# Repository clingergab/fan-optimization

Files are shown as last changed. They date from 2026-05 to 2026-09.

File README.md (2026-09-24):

# fan-optimization

A 3D-printed folding hand fan designed by optimization: Bayesian optimization over 3D unsteady CFD picks
the blade shape, then 3D topology optimization hollows each winning blade into a printable part.

<p align="center">
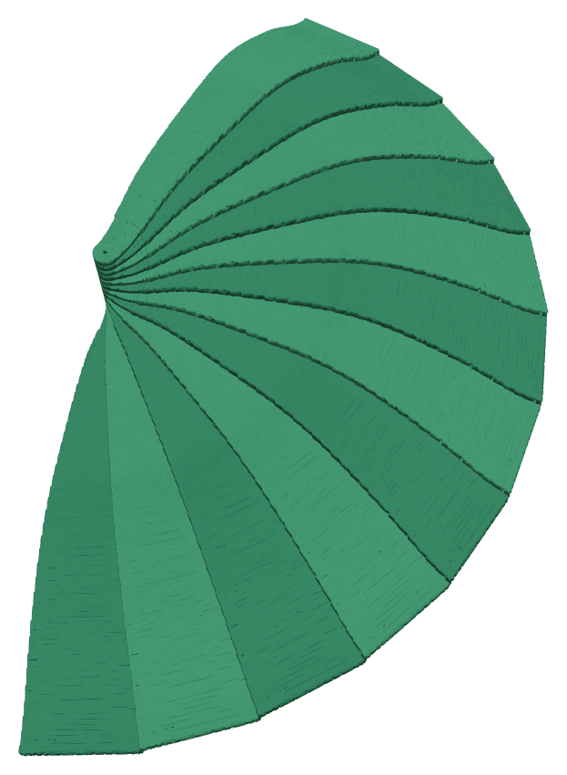
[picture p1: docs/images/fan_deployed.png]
Deployed 12-blade fan
  
  &nbsp;&nbsp;
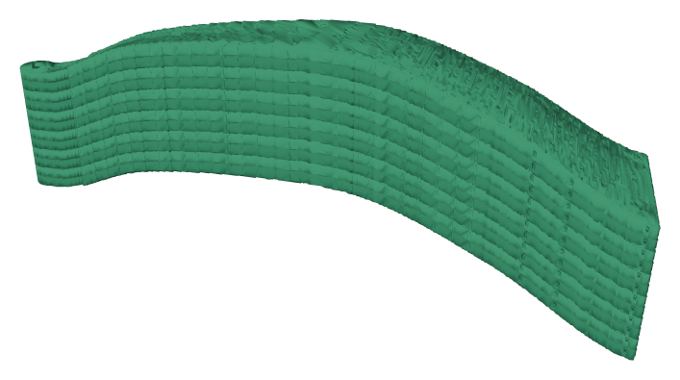
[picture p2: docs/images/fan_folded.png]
Folded 12-blade stack
  
</p>

## Pipeline

1. **Geometry** — CadQuery blade from a 33-parameter codec (rib wave, panel shape, thickness); 12 blades must fold into a ≤ 90 mm stack.
2. **CFD** — SU2 unsteady 3D simulation of the ±40°, 2 Hz stroke; objective `J_fan` = cycle-mean thrust.
3. **Optimization** — BoTorch (qLogNEHVI + TuRBO) over wind ↑, mass ↓, deflection ↓, run across parallel Colab sessions.
4. **Verification** — top designs re-run at fine CFD resolution.
5. **Topology optimization** — per-blade 3D SIMP carves the interior while keeping the aero surface.
6. **Print** — marching cubes → watertight STL → Bambu Studio.

## Status

V1 is done computationally: three blades are ready to print ([print guide](docs/print_guide.md),
[STL files](https://github.com/clingergab/fan-optimization/releases/tag/v1.0-print),
[3D previews](docs/models/)). Next is printing and a blinded feel test against a flat-blade baseline.
V2 plans are in the [backlog](docs/V2_backlog.md).

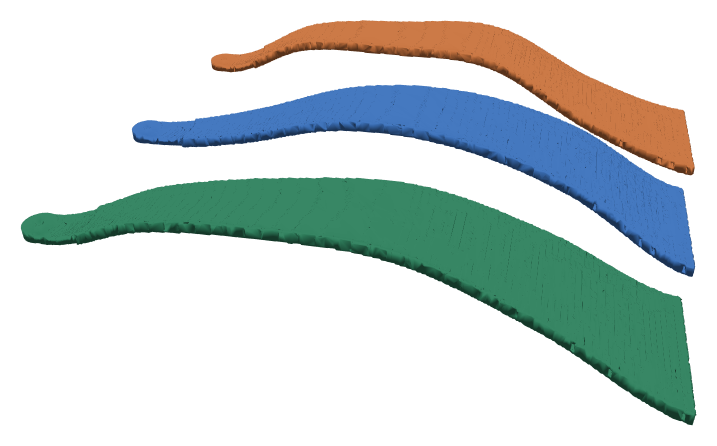
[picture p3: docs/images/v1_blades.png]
The three V1 blades


## Quick start

```bash
conda env create -f environment.yml && conda activate fanopt
pip install -e ".[dev]"
pytest
```

CFD and topology-optimization runs live in [`notebooks/`](notebooks/README.md) (Colab). Design decisions
are in [`docs/adr/`](docs/adr/README.md).

## License

MIT

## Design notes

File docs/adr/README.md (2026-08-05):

# Architecture Decision Records (ADRs)

**This is the single entry point for "what is the current design decision?"** The docs in this
repo accumulated across several major pivots (R11 → V1-slim → aero-first redesign → the 3D-
objective redo). To avoid conflicting or confusing guidance, **read the CURRENT decision for
each topic below**, then follow the supersession chain only if you need the history.

**Convention (lightweight, adopted 2026-07-26):** each major design decision is an ADR with a
Status — *Proposed / Accepted / Superseded*. A new decision that overrides an old one names it
under **Supersedes**; the superseded ADR is marked here and forward-points in its own banner.
Long-form legacy docs are retrofitted as ADRs **by reference** in the ledger below rather than
rewritten. We are not back-filling full ADR files for historical decisions — the ledger + the
current-decision table are enough to avoid confusion.

---

## CURRENT decision, by topic — read these

| Topic | Current decision | Where |
|---|---|---|
| **Optimization approach** (objective, fidelity, BO) | **ADR-0004** — redo on a correct 3D objective (CFz thrust, whole-fan periodic cascade, cold-start coarse→fine BO) | [`0004-optimization-3d-objective-redo.md`](0004-optimization-3d-objective-redo.md) |
| **Blade geometry / architecture** | **ADR-0003** — aero-first solid blade (surface-of-revolution, thick rib + thin panel, N_RADIAL_SECTIONS=40) | [`../blade_architecture_redesign.md`](../blade_architecture_redesign.md) |
| **Phase-2 structural TO** | **ADR-0007** — per-design 3D SIMP on each solid blade (freeze aero skin, carve rib/interior); supersedes the 2D representative-rib TO | [`0007-phase2-per-design-3d-blade-to.md`](0007-phase2-per-design-3d-blade-to.md) |
| **Locked constants** (geometry / kinematics / CFD) | unchanged by the pivot | [`../locks_index.md`](../locks_index.md) |
| **Unsteady CFD regime** | **MACH=1e-9 compressible** (V1, `../locks_index.md §9.4.1`); switch to incompressible **proposed for V2** | [`0006-unsteady-cfd-regime-incompressible.md`](0006-unsteady-cfd-regime-incompressible.md) |
| **Product scope / V1↔V2 split** | unchanged | [`../phase_logs/phase_0_signoff.md`](../phase_logs/phase_0_signoff.md) |
| **V2 / deferred ideas** | backlog | [`../V2_backlog.md`](../V2_backlog.md) |

If two docs seem to conflict, the table above wins.

---

## ADR ledger (supersession chain, newest first)

- **ADR-0008 — Aero BO ranked on rigid geometry (flex-blind ranking)** (2026-08-04). Doc:
  [`0008-flex-blind-aero-ranking.md`](0008-flex-blind-aero-ranking.md).
  **Status: ✅ ACCEPTED — known-limitation record.** Annotates ADR-0004 (does NOT supersede it): the V1
  aero BO ranked designs by `J_fan` on the **rigid** blade (the §2.3 "No FSI" lock), but the panel flexes
  5–15 mm under aero (§3.1) and flex is likely **differential** across designs — so the V1 selection
  *order* is unverified against flex. Fidelity gap, not a wrong-objective error. V1 proceeds (the feel
  test judges the real flexing blade); V1.5/V2 action = one-way FSI across a stiffness spread, re-rank
  finalists before any BO redo. Tracked in `../V2_backlog.md`.
- **ADR-0007 — Phase-2 per-design 3D blade TO** (2026-08-02). Doc:
  [`0007-phase2-per-design-3d-blade-to.md`](0007-phase2-per-design-3d-blade-to.md).
  **Status: ✅ ACCEPTED — CURRENT.** Supersedes the Phase-2 TO *approach* of ADR-0001 /
  `report-final.md` (single 2D representative-rib SIMP by symmetry) — the aero-first solid blade
  (ADR-0003) has no single representative rib, so TO runs **per-design 3D SIMP** on each of the
  top-10 winners (freeze the aero skin, carve rib cores + interior). Retires
  `scripts/run_phase2_to.py`. Geometry, locks, and the optimization redo (ADR-0004) are unaffected.
- **ADR-0006 — Unsteady CFD regime → incompressible** (2026-08). Doc:
  [`0006-unsteady-cfd-regime-incompressible.md`](0006-unsteady-cfd-regime-incompressible.md).
  **Status: 🕐 PROPOSED (V2).** Does not change V1. Would supersede the unsteady-tier MACH=1e-9 regime in
  `../locks_index.md §9.4.1` (Round-9 HIGH-12) if accepted — switching the pitching-fan tier from
  compressible-forced-to-MACH=1e-9 to a truly incompressible solver to remove the low-Mach stiffness that
  drives the ~3h eval cost + divergences. From the `docs/audit_2026-08_toolchain_and_approach.md` retrospective.
- **ADR-0004 — Optimization redo on a 3D objective** (2026-07-26). Doc:
  [`0004-optimization-3d-objective-redo.md`](0004-optimization-3d-objective-redo.md).
  **Status: ✅ ACCEPTED — CURRENT.** Supersedes the *optimization approach* of ADR-0001 and
  ADR-0002. Trigger: an audit found the 2D-slice objective was blind to the rib wave and the 3D
  verification measured the wrong force axis (CFx not CFz) — no design was ever optimized for
  wind. Geometry (ADR-0003), locks, and product goal are unaffected.
- **ADR-0003 — Aero-first blade redesign** (2026-07-19). Doc:
  [`../blade_architecture_redesign.md`](../blade_architecture_redesign.md).
  **Status: ✅ ACCEPTED.** The solid surface-of-revolution blade. Geometry is trustworthy and
  unaffected by ADR-0004; only the scoring layer around it was broken.
- **ADR-0002 — V1-slim** (2026-07-02). Doc: [`../plan_v1_slim_latest.md`](../plan_v1_slim_latest.md).
  **Status: ⚠️ SUPERSEDED IN PART** by ADR-0004. Its single-2D-slice optimization was found
  invalid; its V1↔V2 split and non-optimization scope still hold.
- **ADR-0001 — R11 comprehensive plan** (2026-05-12). Doc: [`../report-final.md`](../report-final.md).
  **Status: ⚠️ SUPERSEDED** by ADR-0002 (for V1 scope) — historical reference only. (Ironically
  its multi-fidelity BO *with 3D tiers* is closer to ADR-0004 than V1-slim's 2D-only cut was;
  the 2D-only shortcut is what caused the waste.)

---

## Adding a new decision
Create `adr/NNNN-slug.md` (next number), set **Status**, list what it **Supersedes**, mark the
superseded ADR here and add a forward-pointing banner to its doc, and update the
**current-decision-by-topic** table above. Keep decisions immutable once Accepted — a change is
a *new* ADR that supersedes, not an edit.

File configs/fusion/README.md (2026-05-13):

# Spike 0.1 — Fusion headless add-in workflow on macOS

**Spec reference:** `docs/plan_R11.md §Phase 0 Spike 0.1` (lines 1785-1789)

**Question:** Can Fusion 360 be driven headlessly from a Python script on
macOS — read `params.json`, regenerate the model, export per-blade STL files
and a STEP file?

**Pass criterion (Spike 0.1):** Fusion launches via the CLI flag, executes
`fan_script.py` against an open one-blade test file, applies User Parameters,
and writes a `SPIKE_0_1_PASS.json` marker plus the requested STL / STEP files
without manual UI interaction.

**Fallback if it fails:** CadQuery becomes the sole geometry backend. Fusion
keeps a role as viewer + post-print manufacturable cleanup but never appears
in the optimization loop.

---

## What's here

| File | Purpose |
|---|---|
| `fan_script.py` | The Fusion script. `run(context)` reads `params.json`, applies User Parameters on the active document, exports STL (per body) + STEP, writes a PASS/FAIL marker. |
| `fan_script.manifest` | Add-in manifest. Use only if you install as an add-in rather than running as a one-shot script. |
| `params.example.json` | Example parameter file. Copy to `params.json` before running. |
| `../../scripts/run_spike_0_1.py` | Headless driver. Validates prerequisites, invokes Fusion with `--runScript`, polls for the marker, reports pass/fail. |
| `../../docs/phase_logs/spike_0_1.md` | Protocol log — fill in as you run. |

---

## Prerequisites

1. **Fusion 360 installed** at the default macOS location:
   `/Applications/Autodesk Fusion 360.app` (or the Fusion 360 admin install).
   The driver script accepts an override path via `--fusion-app`.
2. **A one-blade test file open in Fusion** with these User Parameters
   defined (Fusion → Modify → Change Parameters):
   - `L_blade`, `panel_thickness`, `rib_base_width`, `rib_tip_width`,
     `rib_thickness`, `hub_radius`, `rib_tip_taper`, `pivot_center_x`,
     `click_chamfer_dim`.

   If your test file uses different names, edit `params.example.json` (or
   `params.json` after you copy it) to match — unknown names are recorded
   but not fatal, so partial coverage still produces an export.

   *If you don't yet have a test file:* create a minimal one with a single
   sketched rectangle (`L_blade` × something) extruded by `panel_thickness`.
   Spike 0.1 only validates the workflow plumbing; the geometry detail
   matters in Spike 0.7 (generative-geometry sanity check), not here.

3. **Save the test file once before running** so Fusion has a parent
   document to compute against.

---

## How to run (3-minute procedure)

```bash
cd ~/Projects/fan-optimization

# 1. Copy the example params to the live name (only once)
cp configs/fusion/params.example.json configs/fusion/params.json

# 2. (Optional) edit configs/fusion/params.json with the parameter
#    values you want this run to test

# 3. Open your one-blade test file in Fusion 360 and make it the active
#    document. (Fusion cannot open documents headlessly on macOS — see
#    "Headless caveats" below.)

# 4. Run the driver
python scripts/run_spike_0_1.py

#    The driver:
#      a. confirms Fusion.app exists
#      b. confirms configs/fusion/params.json exists
#      c. clears any stale marker in data/meshes/spike_0_1/
#      d. invokes Fusion with `--runScript configs/fusion/fan_script.py`
#      e. polls for SPIKE_0_1_PASS.json or SPIKE_0_1_FAIL.json
#      f. prints the marker summary and exits with 0 (pass) / 1 (fail)
```

Expected output on success:

```
[spike_0_1] Fusion: /Applications/Autodesk Fusion 360.app/Contents/MacOS/Autodesk Fusion 360
[spike_0_1] params:  configs/fusion/params.json
[spike_0_1] launching Fusion --runScript ...
[spike_0_1] polling for marker (timeout 120 s)
[spike_0_1] PASS — wrote 1 STL + 1 STEP to data/meshes/spike_0_1/
```

---

## Headless caveats (the truth about macOS Fusion)

Fusion 360 on macOS is **not fully headless**. The CLI workflow:

1. Fusion's GUI launches (briefly, can be backgrounded with `open -g`).
2. Fusion loads whatever document is set as the active document — it does
   NOT auto-open a path passed as an argument.
3. The `--runScript` flag executes the named `.py` against the active
   document's Python API context.
4. The script writes its outputs to disk.

Consequences:

- **You must have the test document open in Fusion before you launch
  the driver.** That's the one piece of manual setup. Once it's open,
  the rest is scripted.
- A Fusion window will flash on screen. The driver uses `open -ga "..."
  --args --runScript ...` so it stays backgrounded, but it isn't true
  invisible-headless.
- If you log out / lock the screen during the run, Fusion may stall. Run
  the spike with the user session active.

If Fusion proves too brittle for unattended Phase 4 / Phase 5 batch use,
the spike fail-action is the locked fallback per `§Phase 0 Spike 0.1`:
**CadQuery becomes the sole geometry backend**, Fusion drops to
viewer/cleanup. The fallback path is pre-wired — `src/fanopt/geometry/`
already plans on CadQuery as primary per §3.2 / §9.7.

---

## AppleScript fallback (not implemented for the spike)

The spec lists "fall back to AppleScript UI automation if needed." That
path would script the Fusion GUI through `osascript`:

```applescript
tell application "Autodesk Fusion 360"
    activate
    -- click menu items, type into the parameter dialog, save, export
end tell
```

It's documented here for completeness but **not implemented in this
commit** — if `--runScript` works (the spec's primary path), AppleScript
adds complexity without benefit. Implement only if Spike 0.1's primary
path fails and the fallback decision is to retain Fusion as backend.

---

## Troubleshooting

| Symptom | Likely cause | Fix |
|---|---|---|
| `SPIKE_0_1_FAIL.json: No active Fusion Design document` | The test file isn't open / isn't the active tab | Switch to the test file's tab in Fusion before launching the driver |
| `params.json not found` | Didn't copy the example | `cp configs/fusion/params.example.json configs/fusion/params.json` |
| `missing_parameters` in PASS marker is non-empty | Your User Parameter names differ from the keys in `params.json` | Either rename the Fusion User Parameters, or edit `params.json` to match |
| Driver times out after 120 s | Fusion is hung / your script crashed before reaching `_write_marker` | Open Fusion → Scripts and Add-Ins → Run `fan_script.py` manually; a dialog will show the traceback |
| `Authorization required` dialog from macOS | First-time launch consent | Click Allow once; persists |

---

## What to record in `docs/phase_logs/spike_0_1.md`

After the run, fill in:
- Pass / fail.
- Wall-clock time from driver launch to marker.
- Any `missing_parameters` (schema drift to fix before Phase 1).
- One-line manufacturability eyeball check on the exported STL.

A pass closes Spike 0.1 and unlocks the parallel Spike 0.2-0.5 workflow.
A fail triggers the fallback decision in the next phase-log entry.

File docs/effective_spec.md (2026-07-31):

# Effective Spec (human-readable mirror of `effective_spec.yaml`)

This document is a flattened, current-state-only view of every locked decision in the project. It contains **no history, no superseded options, no amendment cross-references** — those live in Appendix D of `../report-final.md` for traceability.

**Single source of truth:** all production code, CI tests, SU2 templates, and Phase-N launch scripts read from `effective_spec.yaml`. This `.md` file is a human-readable rendering of the same data; the YAML is canonical when the two disagree (CI test `tests/test_audit/test_effective_spec_consistency.py` enforces this).

When a spec changes: update `effective_spec.yaml` first, then this `.md`, then `../report-final.md`. CI fails if test fixtures or code constants reference a value that differs from `effective_spec.yaml`.

**Schema version: 3** (bumped 2026-05-12; v2→v3 covers the C-series sign + projection corrections, H-series operational policies, M-series wording and locking, L-series schema fixes, plus the Z-crank rib-containment + heteroscedastic-purge + JSONL-nullable cleanup batch).

---

> **⚠ SUPERSEDED BY ADR-0005** (trapezoid blade redesign, 2026-07-29..30) — see
> `adr/0005-trapezoid-blade-geometry-redesign.md`. The V1 aero blade is now a **220 mm
> surface-of-revolution TRAPEZOID** (root = 12 mm boss dia at r=0, tip ≈ 51 mm), not the pie-slice
> V-unit. Live overrides of the values below: blade length **200 → 220 mm** (live tip =
> `geometry.blade.RIB_TIP_RADIUS_M`), **blade_count fixed 12** (the {8,10,12} bandit dropped, span
> ≈ 43 cm), **L_wrist_to_tip 0.25 → 0.27 m**, **V_tip 2.20 → 2.37 m/s**, **CFD Re → 43000 / Mach
> 0.0070**, pie-slice width (`r·Δθ`) → Cartesian trapezoid, **mass cap 300 g** (`MAX_TOTAL_MASS_KG`;
> the 100 g C9 text is superseded). The legacy 200 mm values below still drive the retired
> 2D-slice / plano-convex / rib-TO stack.

## Architecture

- **Blade type:** V-unit (2 ribs + 1 panel) — **LEGACY; superseded by the ADR-0005 trapezoid for the live aero path**
- **Material:** single-material PETG except **steel or brass** pivot pin (~2.5 g; PETG pin not permitted)
- **Default n_blades:** 10 legacy → **fixed 12 live (ADR-0005)** (the {8, 10, 12, 14} bandit is dropped)
- **L_blade:** 200 mm legacy parametric length → **live aero blade 220 mm (ADR-0005)**
- **L_wrist_to_tip:** **270 mm** (d_handle + live 220 mm blade tip; **canonical lever arm for τ→F conversions**; ADR-0005, was 250 mm)
- **Pivot architecture:** pin through panel at y = 0; ribs carry no pivot holes.
- **Pivot center (base-relative):** `pivot_center_x = 8 mm`
- **Boss:** 12 mm-OD circular boss × `panel_thickness` centered at `(pivot_center_x, 0)`
- **Keep-out:** `pivot_keep_out_radius = 7 mm` → PANEL_PIVOT_REGION (circular mask)
- **Pin:** 3 mm steel or brass rod, ≥ 45 mm long
- **n_panels_stacked:** 10
- **Wrist axis:** +y
- **Wrist origin:** world (0, 0, 0); pivot at (+0.05, 0, 0). Locked single convention.
- **d_handle:** 0.05 m

## Dimensions and ranges

| Quantity | Value |
|---|---|
| Rib width (base / tip) | 12 / 6 mm |
| Rib thickness | 2.0 mm |
| Panel width between ribs (at pivot end) | 6-8 mm |
| Blade tangential width at radius r | `r · 0.232 − 2·rib_width(r) − 0.5 mm` (panel widens with r) |
| **Panel thickness control points** | **2.2-3.8 mm** (cleanup lock — lower bumped from 2.0 to give the click chamfer 0.1 mm Z-clearance on each side) |
| Panel thickness named derivations | `panel_thickness_pivot`, `panel_thickness_tip`, `panel_thickness_max`, `panel_thickness_mid` |
| Deployed fan extent | **12 × 13.3° ≈ 159.6°** (ADR-0005: blade_count fixed at EXACTLY 12, never more or less; span ≈ 43 cm over the 220 mm blade). Legacy: 10 × 13.3° = 133.3°. |
| Inter-blade angle | 13.3° |
| Folded stack (12 blades) | ≤ 90 mm (ADR-0005 `MAX_FOLDED_STACK_HEIGHT_M`; legacy 10-blade was 22-42 mm) |

## Click features

- **Engagement:** Z-direction lap **with crank z-contained in the rib's z-extent** — `|z_click − z_rib_midplane| ≤ rib_thickness/2 = 0.001 m` (cleanup lock; prevents folded-state collision with adjacent blade's panel)
- **Chamfer angle:** 45° on the rib's top/bottom z-face
- **Chamfer overlap:** 0.5-1 mm
- **Chamfer clearance per side:** 0.1 mm (sets `panel_thickness_min = rib_thickness + 0.2 = 2.2 mm`)
- **Detent radius:** 0.3-0.5 mm
- **Design clearance:** 0.15-0.20 mm per mating surface
- **Naming:** `click_detent` (bare word `detent` reserved for V2-deferred locking)

## Kinematics (H8 symbol-table lock)

| Symbol | Value | Used at |
|---|---|---|
| `f_wave` | 2 Hz | §3.2.3, §9.4 |
| `T_cycle` | 0.5 s | §9.4 |
| `θ_max` | 0.6981 rad (40°) | SU2 PITCHING_AMPL |
| `ω_SHM` | 12.566 rad/s | SU2 PITCHING_OMEGA |
| `ω_blade_max` | 8.8 rad/s | V_tip, V_local |
| `α_max` | 110 rad/s² | §2.4, Filter 2 |
| `V_tip` | 2.37 m/s (ADR-0005; was 2.20) | Re_global, Mach |
| `V_local(r)` | `ω_blade_max · r_wrist` | §3.2.4 BL, C6 multi-radius |
| `Re_global` | 43000 (Tier 0/1; ADR-0005, was 37000) | SU2 cfg |
| `k_reduced` | 0.57 | §3.2.3 |
| `L_blade` | 0.20 m legacy → live 0.22 m (ADR-0005) | TO domain |
| `L_wrist_to_tip` | **0.27 m** (ADR-0005; was 0.25) | **all torque→force conversions** |

**Lever-arm audit:** torque-to-force conversions outside the pivot region MUST use `L_wrist_to_tip = 0.27 m` (ADR-0005; = d_handle + live 220 mm blade tip), NOT `L_blade`.

## SU2 / CFD lock (C2 sign convention)

| Key | Value |
|-----|---|
| MACH_NUMBER (steady tiers) | 0.0070 (ADR-0005; was 0.0064) |
| REYNOLDS_LENGTH (Tier -1) | 0.20 m |
| REYNOLDS_LENGTH (Tier 0, Tier 1) | 0.27 m (ADR-0005; was 0.25) |
| REYNOLDS_NUMBER (Tier -1 / 0/1) | 18000 / 43000 (ADR-0005; was 37000) |
| MOTION_ORIGIN | (0, 0, 0) (wrist-grip at world origin) |
| **PITCHING_OMEGA_AXIS** | (0, 1, 0) — **TIER_SPECIFIC[1] only** (L5 lock; Tier -1/0 have no pitching motion) |
| **PITCHING_AMPL_AXIS** | (0, 1, 0) — TIER_SPECIFIC[1] |
| PITCHING_OMEGA magnitude / AMPL | 12.5664 rad/s / 0.6981 rad |
| AMPL unit | radians (pinned via SU2 build commit; verified by amplitude assertion) |
| **FREESTREAM_PRODUCTIVE** (C2) | **(0, 0, -1)** — air flows -z past stationary fan that's actually being swept in +z toward the user |
| **FREESTREAM_RETURN** (C2) | **(0, 0, +1)** |
| Unsteady ambient velocity (Tier 1) | ≈ 0.001 m/s (near-zero; H10 fallback if FREESTREAM_VELOCITY unsupported: `MACH_NUMBER=1e-9 + REF_DIMENSIONALIZATION=FREESTREAM_PRESS_EQ_ONE`) |
| TIME_STEP / MAX_TIME / TIME_ITER | 0.0025 s / 2.5 s / 1000 |
| n_cycles | 5 (extend to 8 if cycle-2-vs-3 > 5%) |
| J_fan SE | `std / √(n_cycles − 1)` — **diagnostic only, NOT fed to GP** |
| CFL_NUMBER / retries | 10.0 / 1 (halve on retry) |

## J_fan integration (C2 sign-correct two-eval delta)

- Plane Σ: 600 × 600 mm at 300 mm forward of the pivot along +z
- ρ_freestream: 1.225 kg/m³
- t̂ = +ẑ (explicit; **NOT** anatomical "from pivot toward user" phrasing)
- Cycles discarded: 1; integrate cycles 2 through N
- Cycle-2-vs-3 trigger: 5%, floored as `rel = |J2-J3| / max(|J2|, |J3|, 0.10·J_baseline)`
- **Steady-proxy** (C2): `J_fan_steady_proxy = Drag_productive − Drag_return`. A productive louver scores positive. The earlier "Drag_forward − Drag_backward" with `forward = (0,0,+1)` was inverted.

## Material constants

| Symbol | Value |
|---|---|
| ρ_PETG / σ_y_XY / σ_y_Z | 1270 kg/m³ / 45 MPa / **30 MPa** |
| E_PETG_XY / E_PETG_Z | 1300 MPa / 1000 MPa |
| ρ_pin (steel / brass) | 7850 / 8500 kg/m³ |
| **BED_SURFACE** | **smooth_pei** (M13 — Bambu AP05 or equivalent Ra ≤ 5 µm; textured PEI NOT permitted) |
| **Filter 2 p_aero_reference** | **10 Pa** (M3 — fixed canonical baseline; NOT per-design CFD) |

## K_t hotspot table (8 hotspots; bearing 2.00 MPa binds canonical)

| Hotspot | K_t | Mode | Cyclic allowable |
|---|-----|---|---|
| Panel pivot — tension (XY) | 2.42 | tension | 5.58 MPa |
| Panel pivot — bending (XY) | 3.2 | bending | 4.22 MPa |
| Panel pivot — bearing (Z) | 1.5 | bearing | **2.00 MPa** (binds) |
| Click detent (XY) | 3.0 | mixed | 4.50 MPa |
| Click detent (Z-floor) | 3.0 | Z | 2.00 MPa |
| TPMS through-hole | 2.5 | tension | 5.40 MPa |
| Rib-panel fillet | 1.5 | bending | 9.00 MPa |
| Slot end (louver) | 2.0 | mixed | 6.75 MPa |

**§59.5 stress-test load (H9 stagnation pressure):** `p_uniform = p_stagnation_peak = ½·ρ_0·V_local_max² ≈ 3.0 Pa` (canonical); `p_stress_test = 2.5 · p_stagnation_peak ≈ 7.5 Pa`. `V_local_max = ω_blade_max · L_wrist_to_tip = 2.37 m/s` (ADR-0005; was 2.20 at the 0.25 m lever). The 2.5× multiplier stacks on top of the spatial-distribution conservatism of using stagnation pressure (NOT spatial-average F_peak / A_panel).

## Print-frame ↔ deployed-frame mapping (M15 single canonical table)

```
Print frame (build plate at z=0, build direction +z):
  - Bed-contact face: outward normal = -z (faces bed)
  - Top of print: outward normal = +z

Deployed frame (user at +z relative to fan):
  - Aero-functional face (productive +z toward user): outward normal = +z
  - Return-stroke face: outward normal = -z

Rib-flat print orientation:
  - Print bed-contact face → Deployed +z face (calibrated for wall roughness)
  - Print top → Deployed -z face (return; symmetric roughness model)
```

§N7 Check 14 (M1 reworded): "the panel's bottom face (bed-contact in print frame) has its outward normal pointing in −z (into the bed)." The calibrated face is the bed-contact face — no support scars; Ra ≈ 5-10 µm from layer lines + smooth-PEI contact.

## Constraints and Pareto

- m_total < 60 g; r_CoM_wrist ≤ 0.160 m (computed via **XZ-projection** to the +y wrist axis per C1 lock); manufacturability ≥ 0.5
- **4 Pareto objectives:** maximize J_fan (multi-fidelity CFD); minimize I_wrist about +y (deterministic; C4 rationale = peak felt torque, NOT cycle work); minimize peak panel-pivot stress (own fidelity chain); minimize folded form factor (deterministic)

## Filter 2 (three independent modes; H4 hotspot list)

| Mode | Location | Allowable |
|---|---|---|
| Bending | panel skin | 4.22 MPa |
| Tension | hole equator | 5.58 MPa |
| Bearing | pin bore (Z) | 2.00 MPa (binds) |

Hotspot tightening at 0.40× headroom for: **panel pivot all 3 modes + click detent + rib-panel fillet + slot ends + TPMS through-holes + Layer 3 primitive boundaries**. The earlier "any K_t feature within 3 mm of the rib axis" criterion missed the panel-pivot bearing (at y = 0) and is removed.

Tip-deflection prefilter: < 0.6 mm. Reference pressure: `p_aero_reference = 10 Pa` (M3 fixed constant; Filter 2 has no per-design CFD).

## Acquisition pipeline (two-stage MFMO)

1. **qMFKG on J_fan only** (the one objective with CFD fidelity tiers); chooses Tier -1/0/1.
2. **qNEHVI over all 4 objectives at target fidelity** using per-objective surrogates stitched into a ModelListGP.

Per-objective models: `J_fan` MF GP; `i_wrist` / `folded_form_factor` deterministic; `peak_pivot_stress` single-fidelity GP on Filter 2 closed-form.

## Bayesian optimization

| Key | Value |
|-----|---|
| N_DIMS | 37-46 |
| COST_TUPLE | (2.0, 10.0, 50.0) |
| HV_baseline | HV at round 200 (fixed) |
| HV early-stop floor | 500 rounds |
| HV 50-round gain threshold | 1e-4 · HV_baseline |
| Acquisition cap | 35 |
| **K seed at launch** (H3) | from **Phase 3 R²** (2D steady ↔ 2D unsteady): K=3 if ≥0.6; K=4 if 0.5≤R²<0.6; K=5 if <0.5 |
| **K running update during Phase 4** (H3) | from **Spearman ρ² on (Tier 0, Tier 1) overlap**, recomputed every 20 Tier-0 completions, once N ≥ 30 |
| K locked range | {3, 4, 5} (no K=2 path) |
| 1000-h fallback | hold K, force-grow Tier-1 overlap (NOT terminate) |
| ρ freeze threshold | 0.4 (general) / 0.2 (TPMS or noise) |
| GP noise | fixed-floor scalar per tier (NOT per-observation; **CI gate `test_no_heteroscedastic.py`** asserts no stale refs) |
| L7 Tier-1 bias diagnostic | within first 100 Tier-0 evals, if |Δ_TPMS / mean_J_fan_tier0| > 0.30 → switch TPMS/noise architectures to Tier-0-only promotion |

## H5 stop-criteria priority ladder

1. **HV plateau** (50-round gain / HV_baseline < 1e-4 after round 500) → converge + reallocate.
2. **1000-h cumulative compute** → K stays in {3, 4, 5}, force-grow (Tier 0, Tier 1) overlap. **CONTINUE Phase 4, NOT terminate.**
3. **1300-h pessimistic ceiling** → hard stop, hand off current Pareto.

If #1 and #2 fire simultaneously, **#1 wins**. If #2 fires and force-grow completes but BO has not converged by #3, terminate at #3.

## Campaign infrastructure

| Key | Value |
|-----|---|
| Parallel Colab sessions (locked) | 2-4 |
| SU2 procs per session | 5 |
| Retrain interval | 30 min |
| Slice size | 30-60 designs |
| Compute budget (expected/pess/fav) | 600-1100 / 1300 / 300-600 h |
| **Phase 0 sub-spike budget allocations** (H7) | NOT booked against the 1000-h Phase 4 stop rule: Spike 0.6c (H10) ≈ 12 h; Spike 0.7c (H7) 430 h; C6 radial-correction 50 h |
| Stop rule | 1000 h (counted from `git tag phase4-launch`, NOT Phase 0 start) |
| Slice file pattern | `slice_assignments_v{N}.json` (versioned everywhere) |
| Drive pointer format | two-version |
| **Cross-session claim post-open sleep** | **30 s** (M6 lock; bumped from 5 s; Drive consistency window) |
| Drive latency monitoring | P99 > 25 s over 5 consecutive steps → bump sleep to 60 s |
| Schema version | 3 |
| Dedup composite key | `(design_hash, physics_hash, config_hash, material_hash, fidelity, run_direction)` |
| Hash dependency | `physics_hash = blake2b(config_hash ‖ material_hash ‖ motion_blob)` |

## JSONL schema nullability (cleanup CLEANUP-2)

Required all tiers: `design_hash`, `session_id`, `timestamp_utc`, `tier`, `status`, `J_fan`.
Tier -1/0 populate (and Tier 1 NULLs): `J_fan_productive`, `J_fan_return`, `J_fan_delta` (C2-renamed from forward/backward).
Tier -1/0 NULLs, Tier 1 populates: `J_fan_se`, `J_fan_peak`.

## C6 radial-correction calibration (Phase 0; alongside Spike 0.7b)

- 15-20 designs × 3 radii `{0.10, 0.15, 0.20} m`
- Fit `J_fan_corrected = J_fan_at_mid + β · directional_asymmetry_score`
- Artifact: `gdrive/fan-optimization/phase0/radial_correction_v1.json`
- Compute: ~50 h one-time
- Escalation if R² < 0.70: 18 LHS × 3 radii per architecture (360-1080 h fallback)

## H1 Layer 2 enumeration (locked at 20 combinations)

From 32 = 2⁵: drop 6 at {4, 5}-active; drop 4 with both {noise, TPMS}; drop 2 weak singletons. **Production list = 20 profiles.** Pre-commit gate asserts count = 20.

## H6 V1 lock (Spike 0.4 force balance + fallback)

- Pass criterion: `F_friction_cumulative ≥ 2 × F_inertial_at_click`
- `F_inertial_at_click = τ_inertial_peak / L_wrist_to_tip = I_wrist · α_max / 0.27` (ADR-0005; NOT `/0.22` pivot-to-tip, was `/0.25`)
- Fallback geometry: 3 mm × 5 mm × 1.5 mm printed rib-tab on each guard blade
- Flag: `params.layer4.v1_lock_fallback_enabled` (default `False`; auto-armed if Spike 0.4 force balance fails)

## H10 Tier 1 unsteady-config validation (Spike 0.6c)

- **0.6c.1 — cfg sanity:** verify the rendered Tier 1 cfg parses + runs for 1 inner iteration. If `FREESTREAM_VELOCITY = (0, 0, 0.001)` is unsupported, fall back to `MACH_NUMBER = 1e-9 + REF_DIMENSIONALIZATION = FREESTREAM_PRESS_EQ_ONE`. The working syntax becomes the locked Tier 1 cfg.
- **0.6c.2 — benchmark:** NACA 0012 pitching at `k = 0.5-0.6`, Re 30-50k; lift/drag within ±15% of published over 5 cycles (discard 1). Cost ~12 h.
- Phase 4 launch is **gated** on Spike 0.6c passing.

## CI gate additions (§12.0 — newly added by this revision pass)

- `test_units_meters.py` — bounding box matches SI extents; off-by-1000 fails
- `test_r_com_xz_projection.py` — point at (0.1, 0, 0.05) returns ≈ 0.112 m (not 0.1)
- `test_steady_proxy_sign.py` — 45° productive louver → `J_fan_steady_proxy > 0`
- `test_jsonl_tier1_nullable.py` — Tier 1 rows validate with the productive/return/delta nulls
- `test_no_heteroscedastic.py` — purge stale heteroscedastic noise refs
- `test_bed_surface_locked.py` — calibration metadata `BED_SURFACE` matches lock
- `test_click_z_contained.py` — `|z_click − z_rib_midplane| ≤ 0.001 m` for every blade
- `test_lever_arm_uses_wrist_to_tip.py` — torque→force conversions use 0.25 m, not 0.20 m

## Phase ordering (Phase 0 sub-spikes expanded)

| Phase | Name | Weeks |
|---|---|---|
| 0 | Scaffold + Spikes 0.1-0.7 + **0.6c (H10)** + **0.7c (H7)** + **C6 radial-correction** | 1-2 |
| 1 | 4-layer generative geometry | 3 |
| 1.9 | SIMP strip sanity check (**N=30 per branch**, H2) | 3.7 |
| 2a | Baseline 2D CFD | 3.5 |
| 2 | Rib SIMP TO (anchored at rib-panel y-edge) | 4 |
| 2.5 | Rib-panel fillet FEA revalidation | 4.5 |
| 2b | Generative panel optimization | 5-8 |
| 3 | 2D CFD slice | 6 |
| 4 | Multi-fidelity BO (two-stage MFMO; **launch gated on Spike 0.6c + 0.7c + C6**) | 8-10 |
| 5 | Verification + PyFR top-3 | 11-12 |
| 5.5 (step 59.5) | Combined-blade FEA gate (within Phase 5) | — |
| 6 | Print + IMU + acoustic (top 3) | 12-13 |

## Migration policy

- Schema version bumps on any field add/rename.
- `schema_migrations.py` provides `vN → v(N+1)` upgrades for persisted JSONL rows.
- **v2 → v3 migration (2026-05-12):** add r_com XZ-projection; rename JSONL fields `J_fan_forward → J_fan_productive`, `J_fan_backward → J_fan_return`; mark Tier-specific fields Optional[float]; bump panel_thickness_min 2.0→2.2 mm; move PITCHING_*_AXIS to TIER_SPECIFIC[1]; replace ω with ω_SHM / ω_blade_max subscripted symbols; replace §59.5 spatial-average pressure with stagnation-peak; bump Phase 1.9 N=10→30; rewrite W_cycle justification to peak-felt-effort framing; rewrite §N7 Check 14 to "−z outward normal"; lock BED_SURFACE=smooth_pei; lock `p_aero_reference = 10 Pa`; bump Drive post-claim sleep 5→30 s + latency monitoring; add Layer 2 20-combo enumeration; add C6 radial-correction; add Spike 0.6c (H10) + 0.7c (H7) compute booked under Phase 0.
- CI fixtures at `tests/fixtures/effective_spec_v{N}.yaml` preserve prior versions.
- Narrative plan in `../report-final.md` Appendix D records per-decision history; this `.md` and `.yaml` stay current-state.

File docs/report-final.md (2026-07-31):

# Topology Optimization and Aerodynamic Shape Optimization for a 3D-Printed Folding Fan

> ⚠️ **This is ADR-0001, SUPERSEDED (historical reference).** This R11 comprehensive plan was
> superseded by V1-slim (ADR-0002) for V1 scope, and the optimization approach is now governed by
> **ADR-0004** (3D-objective redo). For "what is the current design decision?" start at
> **`docs/adr/README.md`**. Read this doc for background/rationale only.

## Comprehensive Design, Optimization, and Fabrication Guide

**Date:** 2026-05-12
**Revision:** Final spec — V-unit blade architecture, single-material PETG, click-mating, plate-bending rib TO, 4-layer hybrid panel parameterization (~37-46 vars), multi-fidelity BO. Full revision history in Appendix D.
**Scope:** Combined rib structural topology optimization (TO, plate-bending) and **4-layer hybrid generative panel design** (envelope + Fourier modulation, macro-pattern + procedural math fields including TPMS and Perlin/Simplex noise, capped 0-1 primitive, manufacturing categoricals) with ML surrogate modeling for a **fully 3D-printed single-material PETG folding fan with discrete V-unit blades**. ~37-46 design variables optimized via BoTorch (architecture bandit over categoricals + TuRBO over continuous + multi-fidelity GP over CFD tiers, ). **Honest framing:** this is an **expert-priored 4-layer parameterized design study with procedural-math fields for organic variation** — *not* topology optimization in the SIMP / level-set sense. Layer 1's Fourier modulation, Layer 2's 5 hand-picked field types {louver, texture, edge, noise-threshold, TPMS}, and Layer 3's primitive shape library {slot, ellipsoid, wedge} are all human priors; BO searches *within* them but cannot invent a 6th field type or a primitive shape outside the library. Output can produce slatted, lattice, scalloped, swiss-cheese, organic-noise, or solid panels — surprising-looking from inside the parameterization, but bounded by it. No constraint on visual symmetry. Blades click-mate at adjacent outer ribs to form a corrugated deployed surface; folding is pure rigid-body rotation about the shared pivot.

---

## 0. Locked Decisions

> **⚠ Blade geometry locks superseded by [ADR-0005](adr/0005-trapezoid-blade-geometry-redesign.md) (2026-07-29).**
> The geometry/dimension locks below (200 mm pie-slice blade, rib band `[0.020, 0.185]`,
> `blade_count {8,10,12}`, `< 100 g`, panel-pivot `width = r·INTER_BLADE_ANGLE`) are the OLD
> geometry. ADR-0005 is authoritative for the current trapezoid blade (12 blades fixed, 220 mm,
> one-part root, 300 g cap). Non-geometry locks (CFD numerics intent, C11 sign, etc.) still hold.

These are binding inputs to every downstream section; do not re-litigate.

| Decision | Value | Implication |
|---|---|---|
| **Fan architecture** | Discrete V-unit blades with **click-mating panel outer tangential edges** (item #3 panel-edge relocation; the click does NOT live on the rib face — see row 139 below for the full z-lap engagement spec, and §2.2 for the mechanism description) | Eliminates membrane folding; enables true per-blade airfoil optimization |
| **Per-blade structure** | 2 side ribs + 1 wind-generating panel, single rigid piece | One blade = one print, one structural unit; symmetry across blades is exact |
| **Folding mechanism** | Pure rotation about shared pivot; rigid-body blade nesting | No internal blade deformation, no living hinges, no FSI |
| **Inter-blade engagement** | Mating chamfer + detent (default); upgrade to magnetic catch only if cycle testing fails | Self-aligning, FDM-printable, no extra parts |
| **Material** | Single-material PETG except for the pivot pin (steel or brass, ~2.5 g) | Drops multi-material, TPU, AMS toolchanger complexity. The steel/brass pin handles the ~3.6 N·m click-engagement bending that PETG cannot. |
| **Optimization approach** | Four-layer hybrid parameterization: Layer 1 outer envelope + Fourier edge modulation (~14 vars); Layer 2 macro-pattern + procedural math fields with 5-field library (louver, texture, edge, noise-threshold, TPMS), 0-3 active per design (~15-20 vars); Layer 3 capped 0-1 independent primitive (~5-7 vars); Layer 4 manufacturing + click (~3-5 vars). Total ~37-46 vars. | Addresses Mr-Potato-Head alignment, asymmetric-drag access, and OpenCASCADE Boolean reliability. See §6.2.1, §6.2.4, §9.7. |
| **TO scope** | Rib structural TO only (2D plate-bending, Reissner-Mindlin); panel topology is fully driven by Phase 2b's generative parameterization | Density-based TO on the panel and aero-sensitivity-weighted TO were both evaluated and rejected; see §3.1. |
| **What stays preserved (hard constraints in rib TO)** | Rib-panel interface (the rib's junction at y = ±rib_center over the **rib radial band x ∈ [HUB_RADIUS, L_blade − RIB_TIP_TAPER] = [0.020, 0.185] m** per Architectural D / C7 lock) + rib-panel fillet (cyclic mechanical load — the panel-to-rib bending-moment + click-moment transfer flows through here). **NO click-feature footprint in the rib** — the click feature lives on the panel's outer tangential edge in the rib-absent tip region per the item #3 / row 45 relocation. The rib's preserved zones are interface + fillet only, and live only within the rib radial band; the inner 20 mm (HUB region) and outer 15 mm (click region) of each blade are panel-only with no rib material. | Mandatory mechanical constraints; nothing else. Pivot region preserved zone lives in the panel inside the HUB region — see §3.1.2 + below. The dual rib-band lock (C7 inner HUB_RADIUS + Architectural A outer RIB_TIP_TAPER) means the rib is a **bounded middle band**, not a full-length structural element. |
| **Pivot architecture** | Pivot pin runs in +z through the **panel** at y = 0; 10 panels stack on the pin. Ribs do NOT carry pivot holes (they sit at y = ±rib_center, where a single straight z-pin cannot pass through both ribs of one blade). Stack height ≈ 10 × panel_thickness + 2-4 mm spacers ≈ 22-42 mm. | Recovers the ≤50 mm folded-form-factor target. See §2.1, §2.3, §3.1.2, §3.1.5. |
| **Coordinate convention** | Pivot pin axis = world z (stacking direction). Blade planform in XY (200 mm radial along +x, 6-8 mm panel width along ±y). Blade thickness in z. **Wrist rotation axis = +y** (wrist-flexion hinge, perpendicular to the forearm direction +x). SU2 mesh built with **+z toward user**; the **PRODUCTIVE stroke** moves the fan in +z toward the user, which in stationary-fan CFD corresponds to air flowing in **−z** relative to the (stationary) fan: `FREESTREAM_PRODUCTIVE = (0, 0, -1)` / `FREESTREAM_RETURN = (0, 0, +1)` (NOT `AOA` directives — see §9.4). **PITCHING_OMEGA in the rendered SU2 cfg is `(0, -12.5664, 0)` — the NEGATIVE sign on the y-component is part of the locked convention, not just the magnitude** (C11 lock). PITCHING_AMPL = (0, +0.6981, 0). **Kinematic check (locked sign, right-hand-rule convention):** at the SHM instant where the fan is sweeping in +z (productive stroke), the angular velocity vector points in **−y** by the right-hand-rule (curl right-hand fingers from +x to +z; thumb points in −y). So `ω_blade_max = (0, -8.8, 0)` at this instant. For the blade tip at r = (0.25, 0, 0): `v_tip = ω_blade_max × r = (0, -8.8, 0) × (0.25, 0, 0) = (0, 0, +8.8·0.25) = (0, 0, +2.20 m/s)` — the broad face sweeps **in +z** (toward the user), which is the productive stroke. The relative air motion in the (stationary) fan frame is therefore **−z**, matching `FREESTREAM_PRODUCTIVE = (0, 0, -1)`. The earlier draft of this row had the forward proxy at `(0, 0, +1)` and used `ω = (0, +8.8, 0)` — both inverted relative to the right-hand-rule on a productive stroke. The C2 rename + sign correction propagate to §3.2.0, §9.4, §9.4.1, the JSONL schema, and the Jinja2 templates. | All locked CFD numerics (V_tip = 2.20 m/s, Re = 37000, k ≈ 0.57) derive from this convention. See §3.2.0 + §9.4.1. |
| **Rotational-inertia reference axis** | Wrist axis = +y through the handle-grip point at world origin. Pivot pin axis = +z, offset by d_handle = 0.05 m from the wrist axis along +x. CadQuery `i_wrist_about_y` (§6.4) and Spike 0.2 torsional pendulum both measure about the +y wrist axis. Units kg·m². | d_handle offsets the grip from the pivot so I_wrist becomes sensitive to mass placement (mass closer to grip → lower I_wrist); the 20-35% range it adds gives meaningful I_wrist sensitivity. |
| **Mass constraint (C9 relax — was 60 g)** | Total assembly mass m_total < **0.100 kg = 100 g** (hard constraint, not a Pareto objective). The 60 g earlier bound assumed rectangular panel; trapezoidal panel widening (item #35) brings per-blade solid-panel mass to ~20 g × 10 blades = 200 g, requiring ~75% Layer 2/3 carving to fit a 60 g bound — too narrow a feasibility envelope. The 100 g cap admits realistic Layer 2/3 carve rates (40-60%) while still rejecting absurd-mass solutions. | Protects against absurd-mass solutions that happen to be I_wrist-balanced; expands feasibility for trapezoidal panel under #35. |
| **CoM constraint** | r_CoM_wrist ≤ 0.160 m (= d_handle 0.05 m + 0.55·L_blade 0.20 m); same geometric meaning ("CoM no more than 55% of the way out the blade from the wrist") regardless of mass cap. The bound is **distribution-based, not mass-based**, so the C9 mass relaxation does not propagate to r_CoM. | Prevents tip-heavy solutions slipping past I_wrist by being inertia-balanced. |
| **Compute budget** | Colab Pro CPU sessions + Colab Pro GPU (PyFR only); ~600-1100 compute hours expected / 1300 h pessimistic / 300-600 h favorable for Phase 4. **Pre-commit stop rule (locked, single policy ):** at 1000 h with no convergence, K **stays at its current value** within the locked range {3, 4, 5} and the orchestrator force-grows the (Tier 0, Tier 1) overlap by scheduling additional Tier-1 evals on existing Tier-0 points until the K-decision threshold N ≥ 30 is satisfied. **The earlier "drop K from 4 to 2" rule is removed** — K = 2 is outside the locked {3, 4, 5} range, and the force-grow rule already handles the 1000-h deadlock without violating the K range. See §6.2.3. | The favorable case requires K=3 from Phase 3 ρ² ≥ 0.6 AND §6.3.1 prefilter cull rate at the high end. |
| **Compute hardware** | MacBook Pro M3 for local dev + geometry generation + step 59.5 structural FEA + Phase 6 post-processing; Colab Pro CPU (2-4 parallel sessions) for SU2 Tier -1 / Tier 0 / Tier 1; **Colab Pro G4 GPU (95 GB VRAM) for PyFR p=3 top-3 verification only** (T4 is insufficient per HIGH-11 Round-9 lock — 2.5M tets × 100 DOFs/element × fp64 + RK time-stepping buffers + flux storage = 14-18 GB working set; T4 16 GB OOMs, G4 has 5-6× headroom). Tier 1 (~1.5M cells) and Phase 5 verification (~2-3M cells) default to high-RAM CPU. | See Appendix B compute-time table for per-tier hardware and timing. |
| **Multi-objective Pareto** | 4 objectives: maximize J_fan; minimize I_wrist about the handle-grip +y axis; minimize peak pivot stress; minimize folded form factor. Top-3 by Pareto coverage (light corner / knee / heavy corner) are printed and validated in Phase 6. Hard constraints m_total < 100 g and r_CoM_wrist ≤ 0.160 m are NOT objectives. | I_wrist is what the wrist actually feels (τ = I·α); aligns the BO target with Phase 6 IMU `W_cycle = ∫I·ω·dω/dt dt`. |
| **Panel thickness range (4 named control points)** | **3 spline knots at `panel_thickness_t = (t0, t1, t2)`** in **2.2-3.8 mm**. Hard schema bounds: lower `panel_thickness_min ≥ rib_thickness + 2·chamfer_clearance = 2 + 0.2 = 2.2 mm`; upper `panel_thickness_max ≤ 2·rib_thickness − folded_clearance = 2·0.002 − 0.0002 = 3.8 mm`. Four named derivations: **`panel_thickness_pivot = t(pivot_center_x)`** (drives z-stack pitch in the assembled fan), **`panel_thickness_tip = t(L_blade)`** (drives **click-chamfer-depth budget per HIGH-8 Round-9 Option A lock** — the chamfer cuts 0.5-1 mm into the +z and −z corners at the panel's outer tangential edge, NOT a chamfer-z-extent spanning the full panel thickness; see row 139 + §2.2 for full geometry), **`panel_thickness_max = max(t0, t1, t2)`** (drives folded-collision floor), **`panel_thickness_mid = t(L_blade/2)`** (drives J_fan analytical proxies + §3.2.4 corrugation amplitude). The 2.2 mm lower bound gives the click chamfer 0.1 mm of Z-clearance on each side; the "crank" terminology used in earlier drafts referred to a rib-mounted Z-step that is retired under the item #3 panel-edge relocation. | Enables 3D-carved features within the folded-stack collision floor while preserving Z-room for click chamfers. Layer 2/3 carving is excluded from `PANEL_PIVOT_REGION = CircularMask(center=(0.008, 0), radius=0.007)`. The 4-name distinction is mechanical, not a Pareto-axis explosion: the same 3-knot spline produces all four derivations. |
| **Folded form factor target** | 22-42 mm stack thickness at 10 blades. | Recovers the ≤50 mm folded-form-factor target. |
| **Realistic gain target** | 15-30% IMU-normalized J_fan over Spike 0.3 baseline. | Per-blade structural TO 15-30% rib-mass reduction → I_wrist drop; generative panel design 10-25% J_fan; click-feature corrugation 3-8% J_fan. Rotational-inertia savings (not raw mass) flow into the angular-work-per-cycle denominator. |
| **CFD fidelity for optimization** | Multi-fidelity over Tier -1 (2D steady CFD slice, ~10 min/eval — two-eval delta proxy); Tier 0 (3D steady CFD, 30-90 min, ranking-only); Tier 1 (3D unsteady CFD, 3-6 h, true J_fan per §9.4 locked spec). Cost ratios (2, 10, 50). qMFKG over the three tiers. | See §6.2.2 + §6.2.3. |
| **Steady-state proxy** | Two-eval delta: run **PRODUCTIVE** stroke (`FREESTREAM_PRODUCTIVE = (0, 0, -1)`, air flowing -z past a stationary fan that's actually being swept in +z toward the user) and **RETURN** stroke (`FREESTREAM_RETURN = (0, 0, +1)`); `J_fan_steady_proxy = Drag_productive − Drag_return`. A productive louver (slats angled to grab air on the user-ward stroke and feather on the return) scores positive. Symmetric designs score ≈ 0. | The earlier draft labeled `FREESTREAM = (0, 0, +1)` as "forward" — that convention had productive louvers scoring negative and BO would have optimized the wrong sign. C2 rename fixes the inversion. See §9.4.1 Steady-State Proxy. |
| **Cycle count for J_fan integration** | 5 cycles canonical, discard cycle 1 as transient, integrate cycles 2-5 (n = 4 cycles averaged). If cycle-2 vs cycle-3 J_fan differs > 5%, extend to 8 cycles total (discard 2, average 6). **J_fan_se = std/√(n_avg) where n_avg = N_CYCLES − 1** (4 → SE = std/2 at canonical 5 cycles; 6 → SE = std/√6 at extended 8 cycles). **Stored as JSONL `J_fan_cycle_variance` diagnostic only** — NOT fed to the GP as `train_Yvar` (see GP noise model row below). | See §9.4 locked spec + §Phase 3 step 39 decision rule. |
| **Stress-test load case (Architectural C: ω scaling added)** | Add an occasional-peak static load to Phase 2 rib TO and to the Phase 5 step 59.5 combined-blade FEA: **2.5× design-point aero pressure + 2× α_max (220 rad/s²) + 1.41× ω_blade_max (12.4 rad/s vs canonical 8.8)**, applied simultaneously and statically. **Why scale ω:** for SHM at fixed θ_max, doubling α_max (force-driven swing) requires `ω_SHM` to scale by √2, so the peak instantaneous blade angular velocity `ω_blade_max = θ_max · ω_SHM` also scales by √2 ≈ 1.41×. Centrifugal load `F_c = m·ω²·r` therefore **doubles** under stress-test (2× from ω², matching the 2× from α — both stem from the same √2 ω_SHM scaling). The earlier "2.5× p_aero + 2× α_max" spec held ω at the canonical value, which under-estimated centrifugal bearing by 2× under stress-test. Pass criterion: peak σ_VM < 12.4 MPa nominal static (XY at K_tt = 2.42) and < 13.3 MPa (Z bearing), tip deflection < 5 mm, first bending mode > 10 Hz. The **click-detent assertion under stress-test** reads `α · m · r · N = 220 · 0.001 · 0.25 · 10 = 0.55 N` (2× canonical 0.275 N) — overshoots the 0.2-0.4 N budget by 40-175% and triggers a Spike 0.4 magnetic-upgrade decision if Phase 6 testing confirms the load profile. Cyclic per-mode allowables (tension 5.58 / bending 4.22 / bearing 2.00 MPa; §3.1.7) still bind the canonical load. | Represents "user puts their back into it once or twice per session." Designs that pass canonical but fail stress-test are dropped from the Pareto. |
| **Architecture promotion K** | K ∈ {3, 4, 5}. **K is determined by TWO data sources at different phases (H3 lock):** (1) **Seed at Phase 4 launch** comes from **Phase 3's 2D R²** (2D steady ↔ 2D unsteady on the slice): K=3 if Phase 3 R² ≥ 0.6, K=4 if 0.5 ≤ R² < 0.6, K=5 if R² < 0.5. (2) **Running update during Phase 4** uses **Spearman ρ² on the running (Tier 0, Tier 1) 3D overlap**, recomputed every 20 Tier-0 completions; K is updated once N ≥ 30 accumulates in the overlap. The two sources are distinct: Phase 3 R² is the 2D fidelity validity gate (R² ≥ 0.4 floor to retain Tier -1 at all), the Phase 4 running ρ² is the 3D K-decision driver. **N < 30 at the 1000-h trigger fallback:** if cumulative budget hits 1000 h with N < 30 in the overlap, K **stays at its current value** within {3, 4, 5} (no drop to 2) and the orchestrator force-grows the overlap by scheduling Tier-1 evaluations on existing Tier-0 points until N ≥ 30 (typical N=30-N_current Tier-1 evals at 50 cost-units each = ~50-150 extra compute hours). Once N ≥ 30 the K-decision fires normally. | Resolves the deadlock between "N ≥ 30 to decide K" and "1000 h to drop K". |
| **Inner-loop acquisition cap** | 35 TuRBO acquisition rounds per architecture (hard ceiling); early-stop (UCB-improvement < 3% over 5 iters) fires first on convergent architectures. | Worst-case bound; ~10-20% of architectures may marginally improve between 35-50 iterations; the K=4 hedge covers it. |
| **Hypervolume early-stop (4D Pareto)** | After every BO step append the 4D hypervolume; if `(HV[-1] − HV[-50]) / HV_baseline < 1e-4` (i.e., <0.01% of `HV_baseline` cumulative HV gain over the last 50 rounds), declare convergence and reallocate remaining budget to FEA gate top-50 + Phase 5 verification. **Hard floor: 500 rounds** before the check can fire (matches empirical MFBO convergence of 300-600 evaluations for 4D Pareto fronts). **HV_baseline = HV at round 200** (locked; fixed reference, NOT a moving baseline; reference points fixed at Phase 4 launch and never re-computed). The earlier draft used `dHV_per_round < 0.001 · hv_history[-50]` (moving baseline, ~5% per 50 rounds equivalent) which is permissive for 4D MFBO and can trigger early on transient stalls; tightened to `1e-4 · HV_baseline` (~0.01% per 50 rounds) and the floor harmonized to 500. | Threshold pre-registered in `configs/bo_convergence.yaml`. |
| **GP noise model** | **Fixed-floor epistemic noise** (NOT per-observation `train_Yvar`). Solver-noise floor is measured once via replicate Tier-1 runs (same design, perturbed initial conditions) in Spike 0.7b's pre-Phase-4 calibration and locked at `EPISTEMIC_NOISE_FLOOR = max(measured, 1e-6)` for the GP `train_Yvar` constant. **Per-design `J_fan_se` is still measured** and stored as `J_fan_cycle_variance` in the JSONL row for diagnostics, **but is NOT fed to the GP as noise** — physics-driven limit-cycle variance from vortex shedding (5-15% for shed-heavy designs) would otherwise tag the very designs we want to find as low-confidence and weaken the cross-fidelity correlation kernel exactly where asymmetric-drag wins. Tier-specific noise floors are allowed (Tier -1 has higher floor than Tier 1) but each is a *fixed scalar*, not per-observation. | Avoids treating shed-physics signal as measurement noise; see §6.2.3 code block + Spike 0.7b calibration step. |
| **Lock mechanism** | Active locking mechanism is **deferred to V2** (see `docs/V2_backlog.md`). V1 ships with a 3 mm outer-face reinforcement strip on each guard rib + click-feature friction. | If Phase 6 testing shows the fan unlocks under sustained 2 Hz waving, V2 lands a designed lock. |
| **Click-feature footprint (item #3 + rib taper-out + Architectural D HUB_RADIUS — dual rib-band lock)** | 5 × 5 mm patch at the **panel's outer tangential edge at the tip**, in the rib-absent outer band. The rib lives in `x ∈ [HUB_RADIUS, L_blade − RIB_TIP_TAPER] = [0.020, 0.185] m` only — **the inner 20 mm (HUB region) and outer 15 mm (click region) are panel-only**. The click chamfer + detent live in the outer 15 mm panel-only band. Shared constants `CLICK_FOOTPRINT_X_RANGE = (L_blade − 0.010, L_blade)` (last 10 mm — fully inside the rib-absent tip region) and `CLICK_FOOTPRINT_Y_RANGE_PANEL_EDGE = (panel_tangential_outer − 0.005, panel_tangential_outer)` where `panel_tangential_outer = panel_width(r=L_blade)/2 ≈ 0.0225 m` per the #35 widening lock. The chamfer face spans the full panel_thickness in z. Applied to every blade panel's outer tangential edge (inner blades + guard blades alike). **Two new shared constants** in `src/fanopt/geometry/schema.py`: `HUB_RADIUS = 0.020 m` (C7 lock, inner rib boundary) and `RIB_TIP_TAPER = 0.015 m` (Architectural A lock, outer rib boundary). | Panel-edge placement locks adjacent panels into the deployed corrugated surface; rib-mounted clicks were geometrically impossible (z-gap between adjacent ribs is 0.2-1.8 mm under the locked stacking convention) AND would be shielded by the rib's tangential extent even if z were not an issue. The dual rib-band locks make both ends of the blade panel-only: HUB region hosts the 12 mm boss + pivot hole (rib would conflict with boss at r = 0.05, panel_width 11.6 mm < 2·rib_base_width); click region hosts the lap chamfer. The rib is a structural middle band over the radial extent where it's geometrically and mechanically meaningful. |
| **Click design clearance** | 0.15-0.20 mm per mating surface. | Matches Spike 0.4 tolerance-validation range. |
| **Plano-convex envelope (rib-flat print)** | If `print_orientation = rib-flat` (the §7.4.3 default), the Layer 1 envelope is constrained to plano-convex: the bottom face (z = 0 in the build frame) is a single planar surface; all camber + thickness variation goes onto the top face. `deployed-V` orientation relaxes this. | Without the constraint, a 5 mm-camber blade printed rib-flat needs ~4500 mm² of support per blade and post-support Ra ≈ 100-300 µm breaks the §3.2.4 wall-roughness calibration. |
| **Campaign tracker** | Google Drive + per-session JSONL append + pre-sliced round-robin assignment via versioned `slice_assignments_v{N}.json` + content-hashed `current_slice_pointer.txt`. Single-writer GP-acquisition barrier on the M3. Cross-session O_CREAT\|O_EXCL claim sentinel + heartbeat watchdog. | See §Phase 4 step 48, §12.1. |
| **JSONL schema** | One Pydantic-validated row per evaluation with `schema_version`, `design_hash`, `physics_hash`, `material_hash`, `tier`, `status`, `failure_code`, params, mass/CoM/inertia/J_fan/J_fan_delta + per-eval intermediates, stress-test fields, `cfl_max`, retriable + retry_count. | See §Phase 4 step 51 for the full schema. |
| **Compute target line is a favorable case, not a hard ceiling** | Read with the stop rule: at 1000 h cumulative without promoted-arch convergence, K stays at its current value within {3, 4, 5} (force-grow overlap rule above) and the candidate pool narrows top-50 → top-20. **No "K ← max(2, K_required_by_ρ)" path** — K = 2 is outside the locked range. | See §6.2.3 "Honest compute budget." |

---

## Table of Contents

1. [Project Overview: The Folding Fan](#1-project-overview-the-folding-fan)
2. [Folding Fan Geometry and Engineering Constraints](#2-folding-fan-geometry-and-engineering-constraints)
3. [Key Equations and Physical Models](#3-key-equations-and-physical-models)
4. [Software Tools: Easiest Path Analysis](#4-software-tools-easiest-path-analysis)
5. [Claude Code Delegation Map](#5-claude-code-delegation-map)
6. [ML Surrogate Modeling: Core Workflow](#6-ml-surrogate-modeling-core-workflow)
7. [3D Printing Materials Selection](#7-3d-printing-materials-selection)
8. [Step-by-Step Project Execution Plan](#8-step-by-step-project-execution-plan)
9. [Tool Guides and Configuration](#9-tool-guides-and-configuration)
10. [Validation Approaches](#10-validation-approaches)
11. [References and Sources](#11-references-and-sources)
12. [Project Structure and Tooling](#12-project-structure-and-tooling)
13. [Future Work, V2 Backlog, and Baselines](#13-future-work-v2-backlog-and-baselines)

---

## 1. Project Overview: The Folding Fan

### 1.1 What We Are Designing
A folding fan consisting of **N discrete V-unit blades** (default N=10) stacked on a shared pivot pin. Each blade is a **single rigid PETG part** containing 2 side ribs and 1 wind-generating panel between them, printed in one piece. When deployed, adjacent blades' outer tangential panel edges mate via printed click features (chamfer + detent — per item #3 panel-edge relocation, the click lives on the panel edge, NOT on the rib), forming a quasi-continuous corrugated aerodynamic surface (rib ridges separating panel scoops). When folded, blades rotate about the pivot and nest into a V-shaped stack with total folded thickness **22-42 mm at the 10-blade default**, depending on the Pareto-chosen 2.2-3.8 mm panel thickness. Folded form factor is the 4th Pareto objective in §6.4.

> **Footnote (full BO range, MED-10 trimmed):** the architecture-bandit explores n_blades ∈ {8, 10, 12}, so the full Pareto-attainable folded-stack range across the BO is **18-46 mm** (= 8 × 2.2 mm at the light corner to 12 × 3.8 mm at the heavy corner; under the pivot = z convention each blade's Z-extent ≈ panel_thickness ∈ [2.2, 3.8] mm). The ≤50 mm target is recovered across the entire BO range under MED-10. The 14-blade option (would have given 14 × 3.8 = 53.2 mm and 186.2° spread) is removed for ergonomic infeasibility. The design the user picks from the 4D Pareto front determines where in the 18-46 mm range the printed fan lands.

This is fundamentally different from a paddle fan (uchiwa) AND from a traditional sensu/ogi fan:

- **Structural domain:** N rigid PETG blades + 1 pivot pin. Rib TO is one design domain (2D plate-bending via SIMP, §3.1); panel topology is a separate design domain handled by the 4-layer hybrid generative parameterization in Phase 2b (envelope + Fourier modulation + 5-field library of macro-pattern and procedural math fields + capped 0-1 primitive).
- **Aerodynamic domain:** A corrugated rigid surface formed by N panels separated by rib ridges. Surface geometry is driven by the 4-layer parameterization (Layer 1 outer envelope including Fourier-modulated leading/trailing edges; Layer 2 macro-pattern and procedural math fields including TPMS and Perlin/Simplex noise; Layer 3 capped 0-1 primitive). Applied identically to all blades by exact symmetry.
- **Assembly:** N single-material PETG blades + 1 **steel or brass pivot pin** (NOT PETG — per §0 + §2.3 the pivot pin carries a ~3.6 N·m bending moment that a 3 mm PETG pin would fail at σ ≈ 1360 MPa). No fabric, no TPU, no glue, no living hinges, no FSI.
- **Mechanism:** Pure rigid-body rotation of each blade about the pivot pin. Click features on the panel's outer tangential edges engage when adjacent blades reach the deployed angle (per item #3 panel-edge relocation; the rib does not carry click features). Locking mechanism on the guard blades holds the assembly open against any residual click-engagement friction.

### 1.2 Why This Is Harder Than a Paddle Fan
| Aspect | Paddle Fan (uchiwa) | Folding Fan (V-unit blades with 4-layer hybrid generative panel) |
|---|---|---|
| TO design domain | Single continuous plate | One representative rib (2D plate-bending SIMP), applied to all 20 ribs across all blades by exact symmetry. Panel topology is generated by the 4-layer hybrid (not TO). |
| TO problem size | Large (500K+ elements for full blade) | Modest (one rib ~50-150K plate-bending elements); one TO solve per Pareto candidate |
| TO compute time | 2-4 hours per run | 5-30 minutes per rib |
| ASO design space | Planform, camber, thickness distribution | 4-layer hybrid (~37-46 vars): envelope + Fourier LE/TE, 5-field Layer 2 library (louver, texture, edge, noise-threshold, TPMS) with 0-3 active, capped 0-1 primitive, manufacturing |
| CFD complexity | Standard bluff body | Corrugated rigid surface with Boolean cutouts; CFD resolves rib ridges + Layer 2 features. **No FSI.** |
| Structural failure mode | Distributed bending of plate | Rib bending under aero + inertial load (primary); concentrated stress at the pivot hole (secondary); click-feature fatigue (tertiary) |
| Critical stress location | Blade root (uniform plate) | **Three hotspots under panel-pivot architecture, evaluated independently (no scalar superposition):** (1) **Panel pivot hole** (K_tt = 2.42 at d/w = 3/12 = 0.25 in the 12 mm boss; cyclic tension allowable 5.58 MPa, bearing 2.00 MPa Z-direction — **bearing binds first** for canonical loading). (2) **Rib-panel fillet** (K_t = 1.5; cyclic shear/bending where the rib joins the panel; allowable 9.00 MPa). (3) **Click detent at panel outer edge** (cyclic Z-shear from lap engagement; K_t = 3.0; allowable 2.00 MPa Z-floor — single mode; the prior "4.50 MPa XY" line referred to the rib-mounted click and is retired with the item #3 panel-edge relocation). See §3.1.5 K_t hotspot table for the full set. |
| Assembly | Single print | N single-material PETG print jobs (or one large multi-blade print) + 1 pivot pin |
| Print strategy | Single large flat print | Per-blade prints (default), OR full-assembly print if bed size permits |

### 1.3 The Two Optimization Problems
**Topology Optimization (TO, rib only):** For one representative rib (applied to all blades' ribs by exact symmetry; each blade has 2 identical ribs), determine the optimal 2D plate-bending topology via standard SIMP. TO is NOT applied to the panel — panel topology is generated by Phase 2b's 4-layer hybrid parameterization. Plate-bending (Reissner-Mindlin) captures out-of-plane bending under aerodynamic and inertial loading. See §3.1 and Phase 2. Loads come from CFD-derived pressures (closes Open Question #2). Two earlier drafts that did include panel TO (density-based via SU2+Brinkman; aero-sensitivity-weighted plate-bending) were rejected — see §0 and §3.1.

**Generative Parametric Panel Optimization (4-layer hybrid):** Determine the optimal blade panel topology + overall fan geometry. Design space (~37-46 variables, see §6.2.1 for full table):

- **Layer 1 — Outer envelope + Fourier modulation (~14 vars):** camber spline, twist, thickness profile (**2.2-3.8 mm at 3 control points**, hard schema bound), edge profile category, Fourier LE/TE harmonic amplitudes.
- **Layer 2 — Macro-pattern + procedural math fields (~15-20 vars active, 0-3 fields per design):** library of 5 fields — louver / texture / edge feature / **noise-threshold** / **TPMS**.
- **Layer 3 — Capped 0-1 independent primitive (~5-7 vars):** asymmetric point features (slot/ellipsoid/wedge).
- **Layer 4 — Manufacturing + click features (~3-5 vars):** layer height, print orientation, chamfer/detent/clearance.
- **Plus fan macro (~4 vars):** blade count ∈ {8, 10, 12} categorical (spread angle is **derived** from `blade_count × 13.3°` per C8 lock — NOT a free BO parameter; 14-blade trimmed per MED-10), blade length, base rib width, tip rib width.

Total: **~37-46 design variables**, down from a flat ~45-55 Boolean-primitive list in earlier drafts. The 4-layer structure addresses the "Mr. Potato Head" alignment problem, gives the optimizer direct access to asymmetric-drag design families (louvers), and reduces CAD failure rate from ~5% to <2% (safe-by-construction Layer 2). See §6.2.4 for the full rationale.

### 1.4 User Priorities

1. **Minimize cost** -- student budget; free tools strongly preferred.
2. **Minimize effort** -- where "effort" means the user's manual tool-driving and physical-task time, not compute spend or calendar weeks. Scripted/programmatic workflows preferred; Claude Code handles most of the coding.
3. **Maximize results** -- best achievable fan performance within the above constraints.

---

## 2. Folding Fan Geometry and Engineering Constraints

> **⚠ Geometry superseded by [ADR-0005](adr/0005-trapezoid-blade-geometry-redesign.md) (2026-07-29).**
> The dimensions and pie-slice/panel-pivot architecture in this section (200 mm blade,
> `width = r·INTER_BLADE_ANGLE`, rib band `[0.020, 0.185]`, boss at `pivot_center_x`, `< 100 g`
> mass cap) are the OLD geometry. The current locked geometry is the **trapezoid blade** in
> ADR-0005: 12 blades (fixed), 220 mm length, root = 12 mm at the pivot centre (blade+boss one
> part), tip ≈ 51 mm, panel base 3 mm, two modes (panel+ribs / single-thickness no-rib), 300 g
> mass cap. Read ADR-0005 as authoritative where it conflicts with the text below.

### 2.1 V-Unit Blade Fan Dimensions
| Parameter | Value | Notes |
|---|---|---|
| **Blade count** | 10 default; BO range {8, 10, 12} (MED-10 trim: 14 removed for ergonomic infeasibility — 186.2° past straight-line) | Each blade = 2 ribs + 1 panel; tuned in Phase 4 BO |
| **Blade length** | 200 mm | Rib + panel extend full length from pivot to tip |
| **Rib width (at base)** | 12 mm | Tapers to tip |
| **Rib width (at tip)** | 6 mm | Linear taper |
| **Rib thickness** | 2.0 mm | Constrained by FDM minimum feature size |
| **Panel width (between rib pair within a blade)** | 6-8 mm | Per-blade airfoil-shape design variable |
| **Panel thickness** | **2.2-3.8 mm at 3 control points** | Per-element thickness field is set by Phase 2b's Layer 1 envelope generator (§6.2.1, §9.7) and Pareto-traded against I_wrist / folded form factor in §6.4. Hard upper bound 3.8 mm prevents the Z-stacking collision under the pivot = z convention. No TO on the panel — Floor ≥0.4 mm at any local skin for FDM printability. |
| **Blade angular pitch (C8 lock)** | **13.3°** = centerline-to-centerline spacing AND blade tangential width (adjacent blades meet at their tangential edges; no inter-blade gap under the panel-widening lock #35). The earlier "120° fan spread" figure referred to 9 inter-centerline distances × 13.3° (the span from one END blade's centerline to the other END blade's centerline), excluding the half-pitch on each end. | The fan's actual angular extent is **10 × 13.3° = 133.3°** (full 10-blade coverage), not 120°. All downstream consumers (CFD cascade arc-length, J_fan plane sizing, mass distribution, folded silhouette) use 133.3° as the deployed extent. |
| **Deployed fan extent (C8 + MED-10 trim)** | **133.3°** at 10 blades default; BO range adjusts via blade-count axis only **(8 → 106.4°, 10 → 133.0°, 12 → 159.6°)**. The 14-blade option (186.2°, past straight-line ergonomics) is **removed from V1 BO range per MED-10** — a hand fan opened past 180° has end blades behind the wrist axis and is not a practical hand-fan posture. The "spread angle" is NOT a separate BO Pareto axis — it's a derived quantity from blade pitch (locked 13.3°) × blade count. | Earlier drafts treated spread as independent (90-150°) and included 14 blades; under panel-edge meeting at the pitch boundary, spread becomes derived; 14 blades produces 186.2° which is unergonomic and is trimmed from the BO range. |
| **Guard blades (outer 2)** | Same blade pattern + 3 mm outer-face reinforcement strip | Hold fan deployed against residual click-engagement force via the reinforced outer-face strip + click-feature friction; active locking mechanism is a V2 scope item — see `docs/V2_backlog.md` |
| **Pivot hole diameter** | 3 mm | **In the panel at y = 0**, one hole per blade panel (NOT one hole per rib). The pin is steel/brass. d/w = 3/12 = 0.25 in the locked 12 mm-OD boss (the panel is locally thickened to a 12 mm-OD circular boss centered on the pivot hole; without the boss, d/w = 3/8 = 0.375 against the 8 mm inter-rib width, but Layer 2/3 carving cannot reach into the boss per the §9.7.3 PANEL_PIVOT_REGION). |
| **Pivot stack height** | 10 panels × panel_thickness + 2-4 mm spacers ≈ **22-42 mm** | Recovers the ≤50 mm folded-form-factor target without collision. |
| **Pivot location (locked base-relative)** | `pivot_center_x = 0.008 m` from the rib base end (= panel pivot hole center). Boss spans `x ∈ [0.002, 0.014]` (12 mm-OD boss). Shared across all ribs of all blades. The PANEL_PIVOT_REGION circular mask is anchored at this `(pivot_center_x, 0)` and the §9.7 generator reads it as a single named constant — no other coordinate frame (pivot-center-origin, panel-start-origin) is used in production code. |
| **Blade tangential width derivation (item #35 lock)** | At each radial station `r ∈ [d_handle, d_handle + L_blade]`, the blade's tangential span is `tangential_pitch(r) = r · inter_blade_angle_rad = r · 0.232`. At the pivot (r = d_handle = 0.05 m): pitch = 11.6 mm. At the tip (r = 0.25 m): pitch = 58 mm. The blade fully spans its angular pitch: `tip_panel_width(r) = tangential_pitch(r) − 2 · rib_width(r) − 0.5 mm_gap`. At the tip with rib_width_tip = 6 mm: panel_width = 58 − 12 − 0.5 = 45.5 mm (≫ the 6-8 mm inter-rib width near the pivot). The earlier "6-8 mm panel width" was the value at the pivot end only; the panel widens with r so adjacent blades meet tangentially. **Per-blade panel** is a trapezoid (6-8 mm at base, ~45 mm at tip); CFD-relevant J_fan integrates over the trapezoidal area. The mass calc updates accordingly. (Without this widening, the user-reported geometric impossibility holds: 200 mm × 13.3° = 46 mm arc at tip vs the prior 20 mm blade tangential width — 26 mm gap that cannot be bridged by 0.5-1 mm chamfers.) |
| **Click feature: engagement architecture (Option A lock per HIGH-8 Round-9 — 45° chamfered butt joint with detent, friction + detent engagement, NO full-z chamfer face, NO Z-axis overlap)** | The click is a **45° bevel of 0.5-1 mm × 0.5-1 mm** at each panel's outer tangential corner: blade *i*'s panel carries a chamfer cut into its +z face at the outer corner (removing a triangular wedge); blade *i+1*'s panel carries the matching chamfer on its −z face at its outer corner. When the fan is deployed, the two 45° chamfer faces meet at the line `(y = ±panel_tangential_outer, z = z_i + panel_thickness/2)` and form a self-aligning 45° contact. **NO Z-axis overlap is required between adjacent panels** — the chamfered corners touch at a LINE (not a face), and a hemispherical detent bump (0.3-0.5 mm radius) on each chamfer face provides the click engagement via PETG flex during deployment. Force to disengage: 0.5-2 N per click. Engagement is by **friction + detent**, NOT positive Z-lock. **The "lap joint" / "chamfer spans the full panel_thickness" / "panel face overlaps" terminology used in earlier drafts is retired** — adjacent panels do not overlap in z; they meet at a 45° butt joint with detent. **Locked CI:** `tests/test_geometry/test_click_z_lap.py` asserts (a) the chamfer is a small 0.5-1 mm corner bevel (NOT a full-panel-thickness span), (b) chamfer angle is 45° within 1°, (c) no Z-axis overlap between adjacent panels, (d) the chamfer lives at the panel outer tangential edge at `(x = L_blade, y = ±panel_tangential_outer)`. The earlier `test_click_z_contained.py` is deleted in the same commit. | Resolves the geometric impossibility of the prior "Z-axis overlap" lap-joint language. Matches the rest of the spec's friction-engagement intent (Spike 0.4 force-balance criterion `F_friction ≥ 2 · F_inertial`). Fallback if Spike 0.4 shows friction is insufficient: embedded neodymium magnets at the same panel-edge location (~2 g per click pair, ~20 g for 10 blades — within C9 100 g budget). |
| **Click feature: mating chamfer (Option A lock per HIGH-8 Round-9 — small corner bevel, NOT full-z face)** | 45° angle, **0.5-1 mm × 0.5-1 mm bevel** at each panel's outer tangential corner — blade *i*'s panel: chamfer on its +z face at the outer corner; blade *i+1*'s panel: matching chamfer on its −z face at the outer corner. The chamfer is a corner bevel removing a small triangular wedge of material, NOT a face spanning the full panel_thickness. The two adjacent panels' chamfered corners contact at a 45° line at the deployed angle; detent bumps (0.3-0.5 mm radius hemispherical) on each chamfer face provide click engagement. | Chamfered butt joint with detent. Self-aligning during deployment via the 45° contact angle. |
| **Click feature: detent bump** | 0.3-0.5 mm radius hemispherical bump on the panel-edge chamfer face (top +z face of blade *i*'s panel outer tangential edge; bottom −z face of blade *i+1*'s) | Optional retention (graduated to magnetic if cycle test fails) |
| **Click feature: design clearance** | 0.15-0.20 mm per mating surface (z-direction lap clearance, set by FDM Z-axis tolerance) | Compensates for FDM ±0.1 mm tolerance |
| **Click feature: CI regression** | `tests/test_geometry/test_click_chamfer_face.py` — assert the chamfer normal vector on blade *i*'s **panel outer tangential edge** has a +z component (top panel face); blade *i+1*'s matching panel chamfer has a −z component (bottom panel face); both within numerical tolerance. AND `test_click_z_lap.py` (above) for the z-span across panel_thickness. | Catches (a) angular-facing chamfer drift; (b) accidental chamfer relocation back to the rib face. |
| **Panel x-start (panel-pivot architecture)** | `panel_x_start = 0.000 m` from the rib's pivot end | Under panel-pivot architecture the **panel CARRIES the pivot hole** at y = 0, so the panel must extend through `x = 0` (the pivot end) into the pivot region. The panel runs the **full** `x ∈ [0, L_blade] = [0, 0.200 m]`. At `x ∈ [0, 0.020 m]` the panel is locally thickened into the 12 mm-OD circular boss × `panel_thickness` centered at `(pivot_center_x, 0) = (0.008, 0)` (so the boss x-range is `[0.002, 0.014]` for a 12 mm-OD boss centered on the pivot pin at x = 8 mm). The ribs sit at `y = ±rib_center` along the full length. The CadQuery generator (§9.7.1) reads `panel_x_start = 0.0 m` and `pivot_center_x = 0.008 m`. Note: the earlier `panel_x_start = 0.020 m` value was inherited from the pre-panel-pivot rib-pivot architecture (where the panel had to stand off so the rib's pivot hole region was clear) — it is removed under the locked panel-pivot architecture. |
| **Pivot pin length** | ≥45 mm | Includes end terminations |
| **Folded form factor target** | **22-42 mm stack thickness** at 10 blades (= 10 × 2.2-3.8 mm panel-Z + 2-4 mm spacers/end caps; depends on Pareto-chosen panel thickness; see §6.4). The ≤50 mm target is recovered. | 10 blades × **2.2-3.8 mm**/blade (panel Z-extent under pivot = z; ribs are at +Y/−Y edges of the planform and share Z with the panel) — Pareto-trade vs J_fan / I_wrist |

The "rib width" and "panel width" above describe each rib's and panel's *planform-envelope* dimensions. The actual material distribution **within each rib** is determined by Phase 2's plate-bending SIMP TO . The **panel topology** is determined by Phase 2b's 4-layer hybrid generator (envelope + Fourier + macro-pattern/procedural-math fields + capped primitive), not by TO —

### 2.2 Rib Geometry Details

Each rib is a tapered beam **anchored along its full-length rib-panel y-edge** (NOT at a pivot). Under panel-pivot architecture the rib has no pivot hole; bending moments from the panel's aero pressure transfer into the rib along the rib-panel junction at y = ±rib_center. The cross-section at any point along the rib length is the TO design domain.

**Rib-panel BC choice (Phase 2 SIMP TO; Architectural B note):** the rib-panel interface is fixed as a **Dirichlet boundary condition** (all DOFs along the y-edge clamped to zero displacement) against the **smooth-baseline panel placeholder** that the Phase 2 SIMP TO uses internally. This is the **rigid-panel BC** — it assumes the panel is infinitely stiff and turns the rib into a wall-supported plate rather than a cantilever beam. **Limitation:** the real Phase 2b-generated panel (with Layer 2/3 cutouts — TPMS, louvers, noise-threshold) is more compliant than the placeholder, so the Phase 2 rib SIMP TO produces rib material distributions that are slightly **under-built** for the real load (the actual panel transfers less moment because it deflects, so the rib carries more load than the rigid-BC analysis predicted). **Why this is acceptable in V1:** the §59.5 Phase 5 combined-blade structural gate evaluates the full assembly (Phase 2 rib + Phase 2b real panel topology) under the canonical + stress-test loads; any rib design that's under-built for the real panel fails the §59.5 gate and is dropped from the Pareto. The §59.5 gate is the binding correctness check; Phase 2 SIMP TO is screening. **V2 upgrade (queued in §13.3):** replace the Dirichlet BC with an **elastic Winkler-foundation BC** where the rib's z-DOFs at the interface are coupled to a spring stiffness `k_panel` representing the panel's local compliance. Calibrate `k_panel` once from a Phase 0 FEA on a representative skeletal panel.

**Planform envelope (for TO; H12 + Architectural D locks):**
```
Width: w(x) = w_base + (w_tip - w_base) * ((x - HUB_RADIUS) / L_rib)
 w_base = 4 mm at x = HUB_RADIUS (narrow at root)
 w_tip  = 6 mm at x = L_blade - RIB_TIP_TAPER (wider at tip)
 HUB_RADIUS = 0.020 m, L_blade = 0.200 m, RIB_TIP_TAPER = 0.015 m
 Rib radial extent: x ∈ [HUB_RADIUS, L_blade - RIB_TIP_TAPER] = [0.020, 0.185] m
 Rib radial length: L_rib = L_blade - HUB_RADIUS - RIB_TIP_TAPER = 0.165 m

Thickness: h = 2.0 mm (uniform, constrained by FDM layer count)

The TO domain is the 2D tapered planform (length x width) over the rib
radial band only. The inner 20 mm (HUB region) and outer 15 mm (click region)
are panel-only with no rib material.

Up-taper direction (narrow root → wider tip): geometrically motivated by the
widening angular pitch (tangential space available for the rib grows with r);
structurally acceptable because the rib base at r = HUB_RADIUS = 0.020 m has
a short cantilever lever arm to the pivot, so root bending isn't as critical
as it would be for a full-length rib reaching r = 0.

At constant 2 mm thickness, TO determines which portions of the planform are
material vs. void (creating cutout patterns and lightening holes).
See §9.2 for why 2D plate-bending TO (Reissner-Mindlin) is preferred over
3D voxel or 2D plane-stress for this rib thickness.
```

**Pivot region (panel-pivot architecture):** 10 panels stack on the pivot pin along +z; each panel carries a **single 3 mm pivot hole centered at y = 0 on the rib-pair midplane**. The ribs do **NOT** carry pivot holes — under the locked convention (pivot pin = +z, ribs at y = ±rib_center) a single straight z-pin cannot pass through both ribs of one blade. The 8 mm inter-rib panel is locally thickened to a **12 mm-OD circular boss × panel_thickness** centered on the pivot hole (e/d = 2.0 satisfies the pin-tear-out minimum; see §6.3.1 Filter 2). See §2.1 dimensions table, §2.3 blade-assembly, and §3.1.2 preserved-zones for the full architecture spec.
- **The rib's preserved zone is the rib-panel interface** (rib's full-length junction with the panel at y = ±rib_center, where bending moments from aero pressure transfer between panel and rib). Plus the **rib-panel fillet**: a 2 mm × 2 mm cross-section strip running the full rib length at the fillet location, density-clamped to ρ = 1 in the rib SIMP TO; carries the ~0.18 N·m per-rib click-mate moment. §N7 check 15 requires fillet radius ≥ 1.0 mm.
- The pivot-pin-bearing stress concentration (K_tt = 2.42 tension at d/w = 0.25 in the 12 mm boss; K_t_bearing = 1.5 Z-direction) lives in the **panel** per §3.1.5; the rib itself sees its hotspots at the rib-panel fillet (K_t_fillet ≈ 1.5 for ≥ 1 mm fillet) and at slot ends / lock-mech corners (case-by-case K_t).
- The rib must transition from the rib-panel interface to the tapered body smoothly (§N7 check 15 — fillet ≥ 1.0 mm enforces this).
- **CAD-template rename map:** `rib_pivot_hole_diameter` → `panel_pivot_hole_diameter`; any "bottom-of-rib hole" geometry in the §9.7 CadQuery generator / Fusion templates is removed; the generator reads `PANEL_PIVOT_REGION` + drills one panel pivot hole per blade at y = 0 + extrudes the 12 mm-OD boss in `make_panel_solid`. A `tests/test_geometry/test_no_rib_pivot_hole.py` regression check asserts no `rib_pivot_hole_*` parameter remains in `src/fanopt/geometry/schema.py`.

**Guard blade (outer blade) differences:**
- Same airfoil geometry as inner blades but with a **3 mm outer-face reinforcement strip** on the outermost rib .
- **Two rib classes — `inner` and `guard` (paradox fix;.** A single SIMP solve cannot simultaneously enforce mirror symmetry across the inner↔guard interface AND a guard-only locking-mechanism preserved zone — the two constraints contradict. splits the rib TO into **two independent solves**: one for the inner-rib class (8 inner blades × 2 ribs each, mirror-symmetric within the class), one for the guard-rib class (2 guard blades × 2 ribs each, mirror-symmetric within the class but carrying the locking-mechanism preserved zone + the ~3 mm outer-face reinforcement strip). The two solves use independent forbidden-zone masks. Cost ~2× rib-TO time per design — negligible vs CFD. New JSONL schema field `rib_class ∈ {inner, guard}` groups results in post-hoc analysis.
- **V1 lock policy (per §0 lock):** V1 ships **without an active locking mechanism**. The 3 mm outer-face reinforcement strip + click-feature friction holds the fan deployed against the cumulative click-engagement friction across 9 inter-blade pairs during waving. An active locking mechanism is deferred to V2 (see `docs/V2_backlog.md`); V2 will land a designed lock only if Phase 6 testing shows the fan unlocks under sustained 2 Hz waving.

### 2.3 V-Unit Blade Assembly and Click Mechanism
The fan uses discrete one-piece rigid blades. Each blade is a structural unit; the deployed fan is a corrugated surface formed by the click-engagement of adjacent blades; the folded fan is a rigid-body nested stack.

**Blade structure:**

Each blade is a single rigid PETG part containing:
- Inner rib (closer to the next blade in the deployed-counter-clockwise direction): **165 mm × 4-6 mm tapered (narrow at root, wider at tip per H12) × 2 mm thick** (rib lives in `x ∈ [HUB_RADIUS, L_blade − RIB_TIP_TAPER] = [0.020, 0.185] m` per Architectural D / C7 lock; the inner 20 mm and outer 15 mm of the blade are panel-only).
- Outer rib (closer to the previous blade): **same dimensions: 165 mm × 4-6 mm tapered × 2 mm thick.** No click features on the rib — the click chamfer + detent live on the panel's outer tangential edge in the rib-absent tip region (x ∈ [0.185, 0.200]); the boss + pivot hole live in the rib-absent root region (x ∈ [0, 0.020]).
- Panel: **200 mm full L_blade × trapezoidal tangential width × 2.2-3.8 mm thickness at 3 control points** (H13 panel-width formula): `panel_width(r) = r · 0.232 − 2·rib_width(r) − 0.5 mm gap`, valid for `r ∈ [HUB_RADIUS, L_blade − RIB_TIP_TAPER] = [0.020, 0.185 m]` (the rib-present band). Outside this band the panel runs the full angular pitch `r · 0.232` with no ribs and no inter-rib gap (the inner 20 mm hosts the 12 mm boss; the outer 15 mm hosts the click chamfer at the panel's outer tangential edge). Locally widened to 12 mm-OD at the pivot boss centered on x = 0.008 m. Panel topology and porosity come from Phase 2b's 4-layer hybrid generator (§6.2.1, §9.7), not from SIMP TO. - **Panel pivot hole (— one hole per blade panel at y = 0):** 3 mm diameter through-hole at the panel's pivot-region center (x = 0.008 m, y = 0). The pivot pin runs through this hole and stacks 10 panels along +z. **The ribs do NOT carry pivot holes** — they are at y = ±rib_center (different y from the pin) and would not align onto a single straight z-pin even if they did. The panel pivot hole is the critical-stress location at K_tt = 2.42 (d/w = 0.25 in the 12 mm boss); cyclic-fatigue allowables 5.58 MPa tension / 4.22 MPa bending / 2.00 MPa bearing (Z) per §3.1.5 — bearing binds first under canonical loading. Panel-pivot region preserved zone (`PANEL_PIVOT_REGION = CircularMask(center=(0.008, 0), radius=0.007)` in `schema.py`): 7 mm-radius circular keep-out around the pivot pin centerline (covers the full 12 mm-OD boss + 1 mm clearance), excluded from Layer 2/3 generator carving by the §9.7.1 Step 0 panel-domain mask.
- All three parts joined into one rigid body. No internal joints, no living hinges, no flexible elements.

**Pivot assembly:**

**Architecture: pin-through-panel.** Under the locked convention (pivot pin = +z, ribs at y = ±rib_center), a single straight z-pin cannot pass through both ribs of one blade — they sit at *different* y positions. The pin passes through the **panel** at y = 0 instead, one pivot hole per blade panel; 10 panels stack on the pin. Consequences (propagated to §2.3, §3.1.2, §3.1.5, §3.1.7, §6.4):
 - **Pivot stack height: 10 panels × panel_thickness + spacers ≈ 22-42 mm.**
 - The **pivot hole is in the panel, not in the rib** (§3.1.2 preserved-zone moves from rib to panel).
 - §3.1.5 K_t: d/w = 3/12 = 0.25 (12 mm boss centered on the 3 mm pin hole) → **K_tt = 2.42** from the Peterson polynomial. Cyclic-fatigue tension allowable: 0.30 · 45 / 2.42 ≈ **5.58 MPa** nominal; bending 4.22 MPa; bearing 2.00 MPa (Z, σ_y_Z = 30 MPa).
 - The rib's stress concentration is the **rib-panel interface** (rib joins the panel along the rib's full length at y = ±rib_center). The §3.1 plate-bending TO is unchanged — the rib bends under aero pressure transmitted from the panel — but the SIMP preserved-zone mask anchors at the rib-panel interface, not at a rib pivot hole.

**Pivot pin material:** 3 mm steel or brass rod, length ≥45 mm. **Pin bending lever arm correction (item #33 lock):** the bending moment on the pin is `F_click_total · pin_z_extent`, NOT `F_click_total · L_blade`. The pin's transverse loading is the cumulative click-engagement reaction from all 10 panels stacked on it, applied along the pin's Z-extent (22-42 mm stack height depending on panel_thickness). Worst-case: pin = simply-supported beam between its end terminations, distributed transverse load = 9 inter-blade pair clicks × ~2 N peak each ≈ 18 N total, lever arm = stack_height / 2 ≈ 21 mm. Resulting peak bending moment `M_pin ≈ F · L_eff = 18 · 0.021 / 4 ≈ 0.09 N·m` (simply-supported under distributed load). For 3 mm pin: `σ_pin ≈ 32·M / (π·d³) = 32·0.09 / (π·0.003³) ≈ 34 MPa`. **A 3 mm PETG pin at 34 MPa is below the 45 MPa yield but well above the 13.5 MPa fatigue allowable (0.30·σ_y_XY); steel/brass at >200 MPa yield carries the load with >5× safety margin.** The earlier 3.6 N·m / 1360 MPa numbers used `L_blade = 200 mm` as the lever arm, which over-stated the pin bending by ~40× — the steel/brass requirement still binds at the corrected magnitude (PETG would fail in fatigue regardless), but the absolute number was incorrect. The §0 "single-material PETG throughout" rule reads as **"single-material PETG except the pivot pin (steel/brass, ~2.5 g, ~4% of mass budget)."** The non-PETG density of the pin is incorporated in the `i_wrist_assembly` mass-weighted CoM and I_wrist calculation (§6.4 `RHO_PIN ≈ 7850 kg/m³` for steel or 8500 kg/m³ for brass, vs PETG 1270 kg/m³).
3. The two outermost blades are the **guard blades** — same airfoil geometry but with a **3 mm outer-face reinforcement strip** on their outer ribs .
4. **Spacers are FORBIDDEN under the Z-lap click architecture (M18 lock):** the click chamfer + detent on the panel's outer tangential edge engages adjacent panels in a Z-lap with `chamfer_clearance = 0.1 mm per side` (§0 row 33). Any inter-panel Z-pitch addition (a 0.2 mm spacer doubles the chamfer-to-chamfer gap from 0.2 mm design clearance to 0.4 mm actual) would **fully disengage** the click chamfers. The pin stack runs through 10 panels directly under panel-pivot architecture; PETG-on-PETG slip at the panel-panel contact is acceptable at the loads involved. **If Spike 0.4 reveals friction issues during fold/deploy cycles**, the mitigation is (a) tightening the pivot-pin nut to increase axial preload (raises slip threshold), or (b) applying a dry PTFE lubricant to the panel-panel contact faces (reduces μ without altering Z-pitch). The earlier "0.2 mm printed PETG washers between adjacent panels" fallback is retired.

**Click-mating mechanism (inter-blade engagement) — see §0 row 139 panel-edge z-lap lock:**

Adjacent blades engage via **z-direction lap engagement at the panel's outer tangential edge** (NOT on the rib face — rib-mounted z-lap is **geometrically impossible** per §0 row 139: chamfers cannot bridge the 0.2-1.8 mm inter-rib z-gap while staying within the rib's ±1 mm z-extent. Earlier drafts described a rib-mounted "structural crank" — that architecture is retired and the crank concept is gone from V1.). The click is integral to the panel — no separate hardware required.

- **Mating chamfer (locked per item #3 panel-edge relocation + HIGH-8 Round-9 Option A lock):** 45° chamfer of **0.5-1 mm × 0.5-1 mm** at each panel's outer tangential corner. Blade *i*'s panel carries a chamfer cut into its +z face along the outer tangential edge (a small triangular wedge of material removed from the top-outer corner); blade *i+1*'s panel carries the matching chamfer on its −z face along the same tangential boundary (wedge removed from the bottom-outer corner). When the fan is deployed, blade *i+1*'s panel rotates over blade *i*'s panel; the two 45° chamfer faces meet at the line `(y = ±panel_tangential_outer, z = z_i + panel_thickness/2 = z_{i+1} − panel_thickness/2)` and contact at a 45° angle. **No Z-axis overlap is required** — adjacent panels' outer-edge corners touch at a single line; the engagement holds via the 45° contact friction plus the detent bump (next bullet). Self-aligning during deployment. The earlier "chamfer face spans the full panel_thickness in z" / "+z panel face overlaps blade i+1's −z panel face" terminology is retired (Option A lock).
- **Detent bump (default):** 0.3-0.5 mm radius hemispherical bump on the panel's outer tangential edge chamfer face, with matching depression on the mating panel's chamfer. Force to disengage ~0.5-2 N.
- **Design clearance:** `chamfer_clearance = 0.1 mm per side` per §0 row 33 (per-face design clearance). The 0.15-0.20 mm figure referenced in §3.2.2 is the per-face manufacturing clearance including FDM ±0.1 mm tolerance stack — see §3.2.2 line 519 for the full reconciliation.
- **CI gate:** `tests/test_geometry/test_click_z_lap.py` asserts every click chamfer spans `[z_i − ε, z_i + panel_thickness/2 + ε]` where ε is the 0.1 mm chamfer clearance.
- **Fallback if Spike 0.4 shows detent cycle life is insufficient:** upgrade to small embedded neodymium magnets (~1-2 g per click pair, ~20-40 g total for 10 blades; within the C9 100 g mass constraint).

**Folding behavior (no internal deformation):**

When the user closes the fan, each blade rotates about the pivot pin as a rigid body. There is no elastic bending, no spring-back energy stored, no living-hinge stress. The folded form factor is set by:
- **Per-blade Z-extent under convention (pivot = z, blade in XY, thickness in Z):** **2.2-3.8 mm** in z (the panel thickness; the 2 ribs of one blade are at +Y/−Y *edges* of the panel in the XY planform, NOT spaced in Z). The clamp ensures the per-blade Z-extent never exceeds 2·rib_thickness − 0.2 mm so adjacent panels don't collide when folded.
- **Folded stack:** **10 blades × 2.2-3.8 mm in z = 22-38 mm total folded thickness** + **~1-3 mm of end caps only (no inter-panel spacers per M18 lock)** ≈ **23-41 mm overall**. **The ≤50 mm target is recovered.** Folded form factor remains a 4th Pareto objective for designs that push panel toward 3.8 mm vs designs that stay near 2.2 mm.
- Click features disengage during folding (chamfer geometry permits clean separation).

**Engineering decisions logged here:**
- **Decision:** Each blade is one rigid PETG piece; no compliance, no FSI.
- **Reason:** A rigid printable corrugation is fabricable in one shot from a single PETG print, removes FSI from the design loop entirely, and eliminates spring-back failure modes. No compliant-panel sub-study.
- **Decision:** Click features are chamfer + detent printed integral to each **panel's outer tangential edge** (NOT on the rib — see panel-edge z-lap lock above), with magnetic upgrade gated on Spike 0.4.
- **Reason:** FDM-printable, self-aligning, no separate hardware. Magnetic upgrade is a known-good fallback if printed detent cycle life is inadequate.
- **Decision:** Guard-blade locking mechanism is **DEFERRED TO V2**. V1 relies on the 3 mm outer-face reinforcement strip + click-feature friction to hold the fan deployed under the residual click-engagement force during waving. If Phase 6 testing shows the fan unlocks under sustained 2 Hz waving, the V2 backlog (`docs/V2_backlog.md`) is the venue for the lock design.
- **Reason:** Cumulative click-engagement force across 9 inter-blade pairs is non-negligible during high-amplitude waving; a deferred V2 lock is the venue if Phase 6 testing fails.

### 2.4 Structural Loading on Each Blade
Each blade (treated as a single rigid unit comprising 2 ribs + 1 panel) experiences four load types.

**1. Aerodynamic pressure (distributed on the panel surface):**
- Direct surface pressure on the panel; not transmitted through any intermediate compliant layer.
- Each blade's panel carries the full local pressure over its area (no inter-blade load transfer, because adjacent blades are mechanically independent rigid bodies pinned only at the pivot and engaged only at the deployed click position).
- Pressure magnitude: 5-20 Pa at peak waving velocity (~2.5 m/s tip speed).
- **Aero pressure sourcing:** pressure profile comes from Phase 3 baseline CFD on the corrugated rigid geometry. Initial estimates (10 Pa uniform) bootstrap Phase 2 if Phase 3 has not yet completed; one iteration with CFD-derived loads is required if the initial estimate diverges by >10%.
- **Multi-load-case requirement:** Phase 2 rib TO must run **both** peak-positive (push-stroke) and peak-negative (return-stroke) pressure load cases. Pressures are not symmetric in magnitude (push stroke moves more air than return stroke), but the structural design must withstand both extremes within fatigue allowables.

**2. Inertial forces (distributed):**
- Each rib + panel mass oscillates about the pivot axis.
- **Corrected peak angular acceleration:** For SHM at 2 Hz with 40° amplitude, α_max = ω² · θ_max = (2π·2)² · 0.7 ≈ **110 rad/s²**.
- **Inertial loads use wrist-relative r about the +y WRIST axis, NOT the +z PIN axis** (consistent with §6.4's wrist-axis I_wrist). The wrist axis is +y through world origin; the pivot pin runs in +z through the panel at y = 0. **These are two different axes.** The inertial moment arm of a rib mass at `(x_rib, y_rib, z_rib)` under wrist (+y) rotation is `r_wrist = √(x_rib² + z_rib²)`. **Lock:** every `r·α·m` calculation in the structural chain reads `r` from the **wrist axis (+y)**, not from the pin axis (+z). The pin axis is offset by d_handle = 0.05 m in +x from the wrist axis (the pivot at (0.05, 0, 0) vs the wrist origin at (0,0,0)); the perpendicular distance from a rib mass element at (x_rib, y_rib, z_rib) to the +y wrist axis is √(x_rib² + z_rib²), dominated by x_rib (the radial blade length, 0.05-0.25 m) since blade thickness in z is small (≤3.8 mm). At the rib tip x_rib = 0.25 m, r_wrist ≈ 0.25 m; at the pivot end x_rib = 0.05 m, r_wrist ≈ 0.05 m = d_handle.
- **Peak rib-tip acceleration sanity table:** at α_max = 110 rad/s², `a_tip = α · r_wrist_tip = 110 · 0.25 = 27.5 m/s² = 2.8 g`. At the rib midspan (r ≈ 0.15 m): 16.5 m/s² = 1.7 g. At the rib base near the pivot (r ≈ 0.05 m = d_handle): 5.5 m/s² = 0.56 g. These values feed the Phase 2 inertial-load multi-load-case and are recorded in `material_locks.alpha_max_kinematics_sanity` for traceability.
- A 5-gram blade with centroid at 150 mm from the **wrist axis** (= d_handle 50 mm + half-blade 100 mm) experiences F = m·α·r = 0.005 · 110 · 0.15 ≈ **0.083 N** inertial force. A 2-gram rib at 150 mm from the wrist: ≈ **0.033 N**. (Earlier drafts reported 0.055 N / 0.022 N using r = 100 mm measured from the pivot pin, which under-sized the inertial load by ~33% because they omitted the d_handle = 50 mm offset. The Phase 2 `rib_to_solver.py` step 11 inertial-load build, the Phase 5 step 59.5 combined-blade FEA loads, and any other r·α·m calculation in the structural chain must use wrist-relative r.)
- Small compared to aerodynamic load but contributes to fatigue and is the dominant load source at the pivot during direction reversal.
- α_max ≈ 110 rad/s² sets the inertial load magnitudes; downstream values in Phase 2 TO load case (b) and the pivot fatigue calculation in §3.1.5 recompute from the corrected number.

**3. Pivot reaction (concentrated at base):**
- The pivot pin provides a fixed support (moment and shear reaction).
- All loads along the blade resolve to a reaction force and moment at the pivot.
- The 3 mm pivot hole in the panel at y = 0 (one per blade, NOT in the ribs — see §2.1 / §2.2 panel-pivot architecture) is the stress-concentration / failure-prone location.
- Peak bending moment at pivot: M = ∫ q(x) · x dx over the blade.

**4. Click-engagement force (distributed along the panel's outer tangential edge, cyclic; relocated from rib face per item #3):**
- Each time the fan deploys, the outer tangential edge of each blade's panel engages with the next blade's panel outer tangential edge via the click feature (the chamfer + detent live on the panel edge, not on the rib face — see §2.2 click-mating mechanism for the full chamfered-butt-joint + detent engagement spec per HIGH-8 Option A lock).
- Force magnitude: ~0.5-2 N per click event per inter-blade pair (depending on detent geometry; characterized in Spike 0.4).
- Cyclic frequency: once per deploy/fold cycle (~few times per day in typical use; not at the 2 Hz waving frequency).
- Adds a small fatigue-relevant load to the click-feature region of the outer **panel** (per the item #3 relocation; the click is on the panel's outer tangential edge at the tip, NOT on the rib). **Locked location:** `CLICK_FOOTPRINT_X_RANGE = (L_blade − 0.010, L_blade)` × `CLICK_FOOTPRINT_Y_RANGE_PANEL_EDGE` (see §3.1.2b). The Phase 2b 4-layer panel generator (§9.7 `make_panel_solid`) writes the chamfer + detent into this region; the §9.7.3 Check 7 exclusion band prevents Layer 2/3 carving from removing it. **Phase 2 rib TO does NOT carry a click preserved zone** per §3.1.2a — the rib has interface + fillet preserved zones only.

**5. Blade-blade aerodynamic interaction:**
- Adjacent blades shed wakes into each other during waving.
- Not a structural load per se; relevant only to CFD modeling (mesh must resolve inter-blade gaps; CFD post-processor includes all blade surface forces). See §2.5.
- Blade symmetry is exact (no membrane coupling), so per-blade TO requires no sensitivity check.
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

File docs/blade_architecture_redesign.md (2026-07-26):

# Blade Architecture — Design Review & Redesign Proposal

> ✅ **This is ADR-0003, ACCEPTED — the current blade geometry.** Unaffected by the 2026-07-26
> optimization pivot (ADR-0004): the audit confirmed the CAD faithfully honors the wave/camber/
> thickness; only the *scoring* layer around it was broken. One change since: `N_RADIAL_SECTIONS`
> 12→40 (finer meridian). ADR index: **`docs/adr/README.md`**.

**Date:** 2026-07-19 · **Status:** decision document (operator-driven). Triggered by a
design review of the Phase-5-verified blades: the geometry that scored highest on
airflow is aggressive/self-intersecting, the panel is *thicker* than the ribs, and
the fan's foldability is asserted but never verified. This doc consolidates a
three-part investigation (current-architecture audit, data-validity audit, and
folding-fan/two-sided-design research) and proposes a new blade architecture.

---

## 1. Verdict

The current V1 blade architecture has **confirmed, real problems** that make it worth
redesigning **before** spending more compute:
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

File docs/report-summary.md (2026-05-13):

# Executive Summary: V-Unit Generative Design Folding Fan — Rib TO + 4-Layer Hybrid Panel Optimization Pipeline

**Date:** 2026-05-12 | **Revision:** R11 | **Source:** report-final.md

---

## Key Finding

R11 restructures R10's flat ~45-55-var Boolean-subtraction parameterization into a **4-layer hybrid (~37-46 vars)** while preserving every R10 architectural decision (V-unit blades, single-material PETG, click features, plate-bending rib TO, multi-fidelity BO, all 19 prior-review fixes). The change addresses three reviewed concerns: BO can't reliably converge correlated independent primitives ("Mr. Potato Head" alignment problem), rigid hand fans need direct access to angled-louver-style asymmetric-drag design families, and OpenCASCADE Boolean operations on arbitrarily-placed primitives fail too often (~5%
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

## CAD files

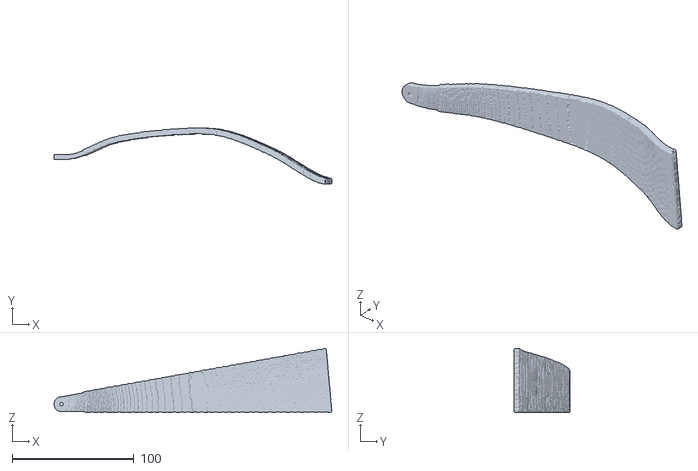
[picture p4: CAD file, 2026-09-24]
docs/models/blade_00_final_preview.stl
228.5 x 46.2 x 53.0

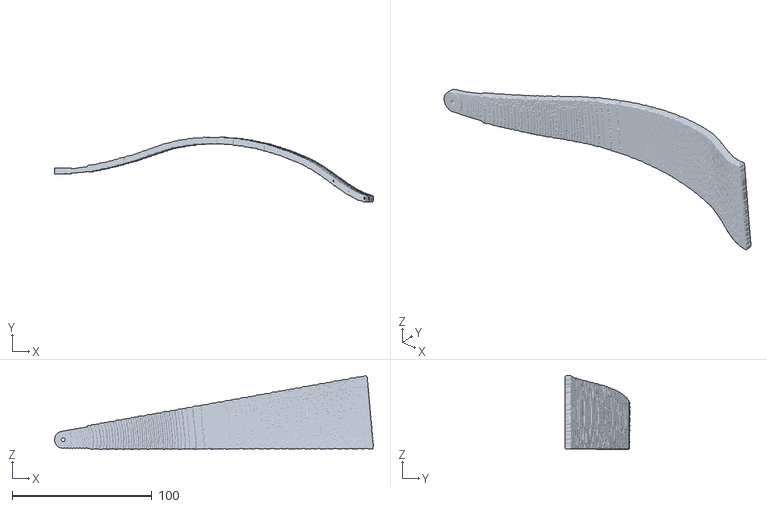
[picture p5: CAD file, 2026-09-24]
docs/models/blade_02_final_preview.stl
228.4 x 46.2 x 53.0

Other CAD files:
docs/models/blade_03_final_preview.stl

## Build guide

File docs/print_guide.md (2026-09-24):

# V1 print guide — Bambu Lab P2S, PETG

Three optimized blade designs; each fan is 12 identical blades threaded on a Ø3 mm pin. Each design is
printed as its own fan and judged in the blinded A/B feel test against the printed flat baseline.

V1 blades — 00 (green), 02 (blue), 03 (orange)

## 1. Files

The full-resolution print files are **not in the repo** (70 MB each). Download them from the
[`v1.0-print` release](https://github.com/clingergab/fan-optimization/releases/tag/v1.0-print).
Lightweight previews (150k faces, < 0.4 mm deviation, viewable in GitHub's 3D viewer) are in
[`docs/models/`](models/).

| Print file | Role | Rib restore width | Folded stack | Pin |
|---|---|---|---|---|
| `P2C_blade_00_ribadd.stl` | **best wind** — marginal on stress (FOS ≈ 1.9) and fold (0.5 mm under the 90 mm cap) | 2.0 mm | 89.5 mm | Ø3 × 60 mm |
| `P2C_blade_02_ribadd.stl` | **best structure** | 1.5 mm | 88.1 mm | Ø3 × 59 mm |
| `P2C_blade_03_ribadd.stl` | **clean** all-rounder | 2.0 mm | 86.1 mm | Ø3 × 57 mm |

Also in the release: `P2C_blade_00_ribadd.3mf` (Bambu Studio project) and
`P2C_blade_00_ribadd.gcode.3mf` (sliced plate for the P2S), plus the raw topology-optimization output
`P2C_blade_{00,02,03}.stl` before rib restore (reference only — do not print).

All print files are in millimetres, pre-oriented **on-edge**, bbox ≈ 228 × 46 × 53 mm (fits the P2S
256³ mm volume). "P2C" in the filenames is a historical typo for P2S — the files are correct.

**What the blade is:** the hollow topology-optimized (TO) shell — two thin aero faces joined by solid
leading/trailing-edge ribs, with a hollow core. The TO had carved the edge ribs away toward the tip
(the faces came apart there), so the `_ribadd` files restore the rib only where it was fragmented
(≈ 34–40 % of each edge, mostly the last ~55 mm) and add a 0.6 mm cosmetic tip-end cap. The core is
intentionally left hollow.

## 2. Slicer settings (as used in the sliced 00 project)

| Setting | Value |
|---|---|
| Printer / nozzle | Bambu Lab P2S, 0.4 mm stock nozzle |
| Filament | Generic PETG @BBL P2S |
| Nozzle / bed | 255 °C / 70 °C |
| Plate | Textured PEI |
| Layer height | 0.20 mm |
| Walls | 2 loops |
| Infill | 15 % grid |
| Supports | on, normal (auto), top Z-gap 0.2 mm |
| Brim | auto, 5 mm |

## 3. Plate plan and estimates

- **3 blades per plate** → 4 plates per fan (12 blades), 12 plates for all three designs.
- Slicer estimate for design 00: **~7.6 h and ~60 g PETG per plate** (incl. supports) →
  roughly **30 h and ~240 g per fan**, ~0.75 kg for all three fans.

## 4. Assembly (per fan)

1. Peel supports and brim; deburr the bore ends and the brim edge.
2. Ream the bore to Ø3 mm if it printed under, or use a Ø2.9 mm rod for a light sliding fit.
3. Thread 12 blades on a Ø3 mm steel/brass pin (length per §1), **all the same way up** (camber in the
   same direction) so they nest in a clean z-stack.
4. Cap both ends (cap / washer / push-nut) with light axial preload — friction holds the fan open at
   any angle. There is no click detent in V1 (a hub detent was found geometrically infeasible).

## 5. Before committing 36 blades

1. Print **one** blade: check that supports peel cleanly and the thin edges are acceptable.
2. Print a **pair** + pin: check that the blades nest when folded and deploy freely.
3. Design 00 in particular is 0.5 mm under the fold cap — confirm 12 of them actually stack before
   printing the full run.

## 6. Known V1 limitations

- **Flex:** the TO minimized compliance only, so it hollowed the core with no internal webs; the
  blades will flex. V1.5 fix: re-run TO with a stiffness objective + buckling constraint
  (`V2_backlog.md`).
- **Ranking was flex-blind:** designs were ranked on rigid-blade CFD (ADR-0008); the feel test judges
  the real, flexing blade.
- **Hub root is un-optimized CAD** (the TO clamped a retired 20 mm hub band) — sound for V1, fixed in
  V1.5 (`V2_backlog.md`).

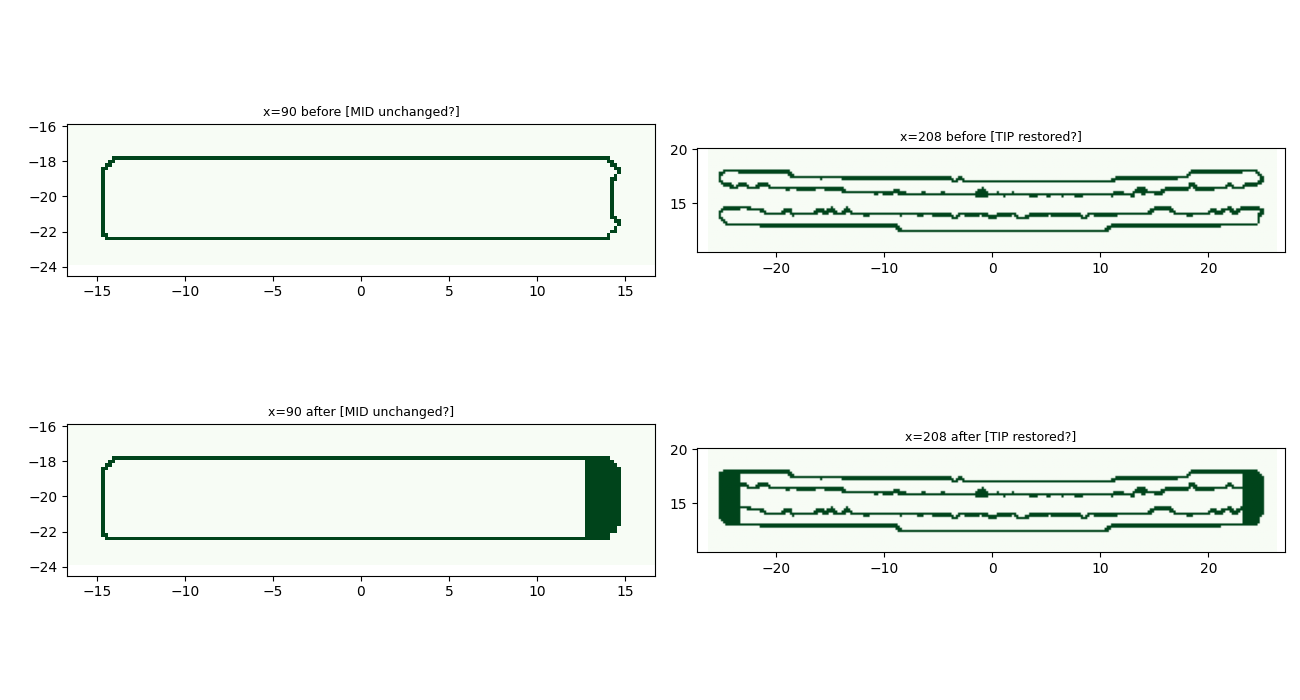
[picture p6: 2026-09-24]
docs/images/print_checks/ribtip_check.png

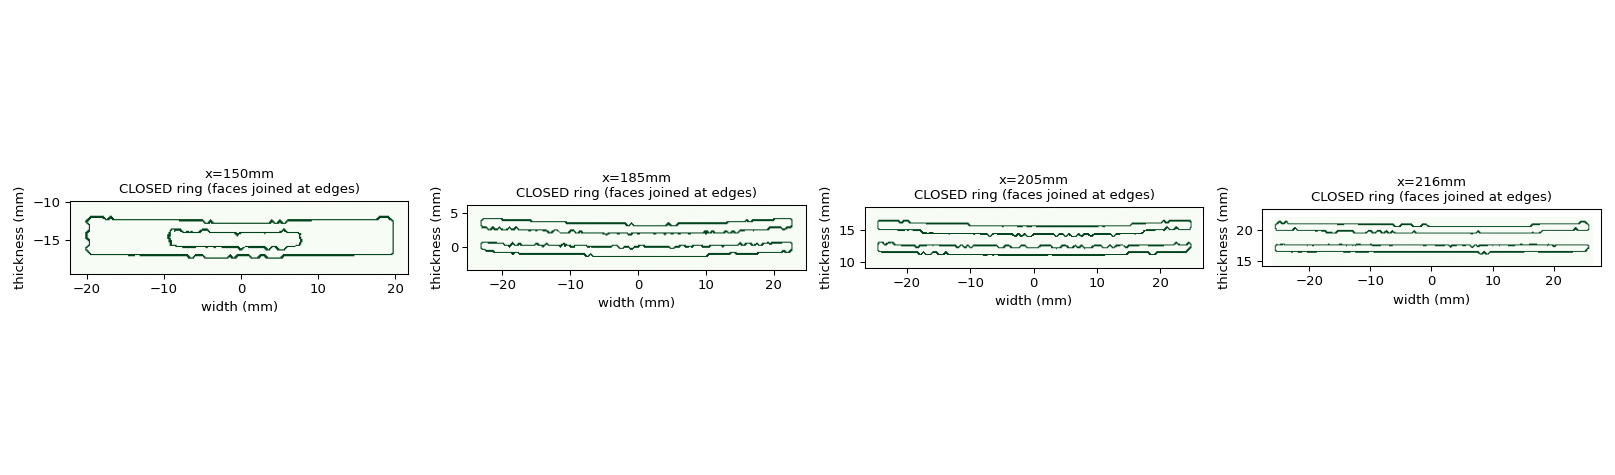
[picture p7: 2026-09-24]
docs/images/print_checks/tip_xsec.png

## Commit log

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2026-05-14 Spike 0.6c notebook: fix Colab-VM issues found during first live run
    Three bugs surfaced when running the notebook on Colab Pro CPU:
    1. SU2 binary install: when the SU2 v8.0.1 zip lays `bin/SU2_CFD` at the
    top level of the extracted tree, `rglob('SU2_CFD')` found the
    canonical path. The previous code then unlinked the real file and
    created a symlink pointing to itself, which triggered ELOOP on the
    subsequent chmod. Fix: skip symlinks in the rglob, and compare
    resolved paths before deciding whether a symlink is needed.
    2. gmsh import failure on a fresh Colab VM: the gmsh wheel dlopens
    libGLU.so.1 and X libs at import time, none of which Colab Pro CPU
    runtimes ship by de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
2026-05-14 Spike 0.6c: fix NACA 0012 airfoil self-intersection in gmsh meshing
    The previous build_naca0012_mesh constructed the airfoil from a single
    gmsh.addSpline interpolating all 200 cosine-spaced points. At the
    trailing edge — where the upper and lower surfaces meet at a ~6° angle —
    the spline overshoots the corner and self-intersects, sending gmsh into
    an infinite "split-and-retry" loop:
    :-( There are 2 intersections in the 1D mesh (curves 1 1)
    8-| Splitting those edges and trying again - level 0
    :-( There are 2 intersections in the 1D mesh (curves 1 1)
    8-| Splitting those edges and trying again - level 1
    ...
    Fix: connect the cosine-spaced points with individual line se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
2026-05-14 airfoil_polyline: fix LE→TE traversal order for the lower surface
    The previous code built the lower surface in TE→LE order:
    lower = [(x, -y(x)) for x in reversed(xs)]
    return list(reversed(upper)) + lower[1:-1]
    so the combined polyline went TE → upper → LE → BIG JUMP back to
    near-TE on lower → traverse lower toward LE → close back to TE.
    The two big chord-spanning straight jumps (LE → near-TE-on-lower, and
    near-LE-on-lower → TE) cross each other inside the airfoil interior,
    which manifests in gmsh as:
    Info: :-( There are 2 intersections in the 1D mesh (curves 200 398)
    Info: 8-| Splitting those edges and trying again - level 0
    The first iteration o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
2026-05-14 Spike 0.6c: switch SU2 unsteady cfg to REF_DIMENSIONALIZATION fallback
    SU2 v8.0.1's parser rejects FREESTREAM_OPTION = FREESTREAM_VELOCITY
    ("invalid option value FREESTREAM_VELOCITY. Did you mean DENSITY_FS,
    TEMPERATURE_FS?"), verified empirically by Spike 0.6c.1 on Colab Pro
    CPU. The Round-9 HIGH-12 lock explicitly anticipates this case:
    > If FREESTREAM_VELOCITY is NOT a valid directive in the deployed SU2
    > build, replace with MACH_NUMBER = 1e-9 + REF_DIMENSIONALIZATION =
    > FREESTREAM_PRESS_EQ_ONE + reference state. Document the working
    > syntax in §9.4.1 as the locked Tier-1 reference cfg.
    This commit flips both templates (fan3d_unsteady.cfg.j2 and
    oscillating_airfoil_benchmark.cfg.j2)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
2026-05-14 Spike 0.6c.2: replace literature gate with internal-consistency gates
    Targeted literature survey (2026-05) confirmed the (Re=40k, k=0.55,
    ±10°, mean α=0°, c/4 pivot) operating point is in a gap between the
    well-studied low-Re/low-k attached-pitching regime (Kim & Chang 2013)
    and moderate-Re/high-k dynamic-stall regime (MDPI 2025, McCroskey/Carr
    at Re~10⁶). Nearest neighbors disagree on amplitude, k, and Re; at
    this Re inter-study scatter on C_L_max is ≥25%. The hand-typed
    NACA0012_REFERENCE placeholder values (C_L_max=1.20, C_d_mean=0.085,
    hysteresis=0.45) are likely ~2× too high — those belong to the
    high-Re McAlister/Carr regime. The ±15% literature-comparison gate
    is not defen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
2026-05-14 Phase 1 orchestration scaffold + §9.7.3 manufacturability filter
    Pure-Python orchestration scaffold for the 4-layer hybrid generator,
    plus the §9.7.3 (§N7) 14-row manufacturability filter protocol. Real
    CadQuery shape construction stays as Phase 1 follow-up work; today's
    scaffold returns dict-descriptions so the orchestration logic and
    filter contract are testable + freezable now.
    generator.py:
    - BladeDesignParams retained (4-layer aggregator with cross-layer
    plano-convex check).
    - generate_blade(params) -> GenerationResult: applies Layer 1 → 2 → 3
    → 4 in the fixed order specified by plan §9.7 (Layer 2 fields apply
    TPMS → noise → louver → texture → edge to avoid orde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
2026-05-14 ruff / black / mypy sweep across the repo
    Mechanical lint / format / type sweep, dominated by black reformatting
    of files touched throughout Phase 0 + today's Phase 1 prep work. No
    behaviour changes; tests/audit/inline-import gates unchanged from
    pre-sweep state.
    pyproject.toml — config tweaks:
    - ruff.lint.ignore += {RUF001, RUF002, RUF003}: the × multiplication
    sign appears legitimately throughout scientific-notation docstrings
    (e.g., '20 mm × 20 mm panel', '5 mm × 5 mm click footprint'). Ruff
    flagged ~120 of these as 'ambiguous Unicode'; they are NOT bugs.
    - mypy.disable_error_code += [import-untyped]: silences the yaml
    'Library stubs not installed' note in test_no_stale_arch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
2026-05-14 Phase 1 Layer 1: CadQuery envelope generator + scaffold wrapper
    Lands the first real-shape generator code in Phase 1. The scaffold from
    the earlier commit returns dict-descriptions only (no CadQuery
    dependency); this commit adds CadQuery shape construction in two new
    modules that hard-require cadquery + a wrapper that bridges them.
    src/fanopt/geometry/envelope_cad.py — Layer 1 envelope (full):
    - make_outer_envelope(params: Layer1Params, print_orientation: str) -> cq.Workplane
    - Cross-section loft: N_RADIAL_STATIONS=20 slices along x ∈ [LOFT_START_EPS_M,
    L_BLADE_M], each a closed polyline of 2*(N_CHORD_SAMPLES+1)=66 vertices
    in (y, z). The 1 mm loft-start offset avoids the degenerate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
2026-05-14 Layer 1 review fixes: Fourier phases + tighter tolerances + missing tests
    Self-review of the previous commit found one critical bug and several
    test/documentation issues. Fixes all 10 items flagged in the review.
    CRITICAL — Fourier phases now match plan §6.2.1:
    - Plan locks "phases fixed at 0, π/3, 2π/3" for k=(1, 2, 3) Fourier
    harmonics. The previous implementation used phase=0 for all k, which
    diverged from the plan's spec and would have produced different
    envelopes than the plan-faithful BO design space.
    - Added FOURIER_PHASES_RAD = (0, π/3, 2π/3) as a locked exported
    constant; _fourier_modulation now uses sin(kπx/L + φ_k).
    - Replaced test_fourier_zero_at_endpoints (whic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
2026-05-14 Spike 0.6c: regime diagnostic for the moving-body-in-still-air cfg
    Cell 8's first run produced CL values of O(10^6) with c_l_min positive
    throughout cycles 1-4 — non-physical for a symmetric NACA 0012 pitching
    ±10° about α=0°. Root cause hypothesis (still under verification): the
    benchmark cfg copied the production Tier-1 MACH=1e-9 numerics, but a
    NACA 0012 oscillating-airfoil benchmark needs wind-tunnel-frame
    numerics (non-zero freestream) to produce conventional aerodynamic
    coefficients. The 2026-05-13 symmetry gate implicitly assumed
    wind-tunnel physics; it doesn't apply to body-in-still-air added-mass
    force regimes.
    This diagnostic verifies the hypothesis CHEAPLY (uses existing Ce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
2026-05-15 Fix colab_spike_0_6d.ipynb: real SU2 installer + correct repo/branch
    The notebook's Cell 5 was stripped to a Drive-cache check only and
    never installed SU2 — sub-spike 0.6d.2 (the 2D thin-plate SU2 run)
    could not run. Cell 1 also had wrong constants (SU2_VERSION='v8.0.1'
    double-prefixed the installer; no SU2_DIR; SU2_BIN at the wrong path;
    missing urllib.request import) and Cell 2 cloned the wrong GitHub org
    (gclinger vs clingergab) off main (the 0.6d code is on the feature
    branch, not main).
    - Cell 1: ported the proven 0.6c constants (SU2_VERSION='8.0.1',
    SU2_DIR, SU2_BIN, GIT_REPO/BRANCH/USER/EMAIL); consolidated imports
    - Cell 2: clone the spike-0-6d-tier1-quant-sanity branch + asser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
2026-05-16 Fix colab_spike_0_6d.ipynb Cell 3: install gmsh + native libs
    Cell 3 only did `pip install -e .[bo]` and never installed gmsh, so
    scripts/gen_benchmark_meshes.py (the 0.6d.2 thin-plate mesh generator)
    hit ModuleNotFoundError: No module named 'gmsh'. Ported the proven
    0.6c dependency cell: apt-get the libGLU/X native libs gmsh dlopens at
    import, then pip install gmsh + the scientific stack, while keeping the
    sys.path additions the in-notebook script imports rely on.
    Also corrected Cell 6's FileNotFoundError message — it told the
    operator to "run the Spike 0.6c notebook Cell 8" if the Drive
    history.csv is missing, but Cell 8 is the deferred 6-12h benchmark we
    explicitly do not want re-run.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
2026-05-16 Redesign Spike 0.6d gate: added-mass frequency-consistency (option A-lite)
    The first live Colab run exposed that the original 0.6d.1-gating design
    was unsound: its magnitude check compared SU2's q_ref=1 nondimensional
    CFx against a dimensional Newton envelope (the ~6-order gap is the
    nondimensionalisation, not proven non-physical output), and its
    near-zero-cycle-mean symmetry criterion is ill-posed for a fan that
    produces net force by design.
    Rebuild the gate around a single normalization-invariant, parameter-free
    falsification test — Sub-spike 0.6d.2, redesigned:
    - Run the 2D thin-plate at TWO pitching frequencies (ω₁, ω₂), same
    plate/pivot/θ_max.
    - Fourier-project each m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
2026-05-26 Fix Colab spike-0.6 notebook bugs
    * 0.6c notebook Cell 10: rename undefined REPO_ROOT to REPO_DIR
    (the constant defined in Cell 1) so the aggregator cell runs.
    * 0.6d notebook Cell 9: guard the sub_2_result.json + results.json
    reads so the aggregator's "sub_2 is required" diagnostic surfaces
    instead of being buried under a misleading FileNotFoundError.
    * 0.6d 2D thin-plate cfg: rotate about z (not y) for the x-y-plane
    mesh. Rotation about y on a 2D x-y mesh is quadratic in theta -
    no first-order sinusoid - so CMz never oscillates and the Fourier
    projection returns 0 (which the analyzer was misreporting as a
    missing moment column). The C11 literal y-sign-lock applies only
    to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
2026-05-26 Pin colab_spike_0_6d.ipynb to GIT_BRANCH=main
    The 0.6d work is merged to main (PRs #10, #13) and the renderer
    y->z fix is also on main. Cloning the stale spike-0-6d-tier1-quant-
    sanity feature branch gave Colab an old fanopt with the y-axis
    renderer signature, causing TypeError on Cell 7 after the notebook
    itself was updated to pass pitching_omega_z.
2026-05-26 docs: refresh Phase 0 status for current 0.6c+0.6d gate semantics
    * phase_0_signoff.md "Action items remaining" — rewrite to match
    the post-2026-05-15 Note 3 redesign: 0.6d.2 is the SOLE gate,
    0.6d.1 + 0.6d.3 advisory; 0.6c.1 PASS comes from the 0.6d
    notebook Cell 5b history.csv-evidence path (no stdout-capture
    fix needed). Map operator steps to actual Colab cells.
    * phase_checklist.md — drop stale outer_steps=0 references for
    0.6c.1 (recovered 2026-05-21 via the evidence path); drop the
    pre-merge `redesign-0-6d-added-mass` branch references (now on
    main, with the 2026-05-21 y->z pitching-axis follow-up); switch
    Phase 0 signoff bullets from "Spike 0.6c is the one real ga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
2026-05-26 Land Layer 3 primitive_cad + wire into generator_cad
    * src/fanopt/geometry/primitives_cad.py — apply_primitive(shape,
    primitive) builds a slot / ellipsoid / wedge, applies extrinsic
    X->Y->Z rotation + translation, then Boolean cut (subtract) or
    union (add). 100% line coverage from 16 tests in
    tests/test_geometry/test_primitives_cad.py.
    * src/fanopt/geometry/generator_cad.py — call apply_primitive after
    make_outer_envelope, wrapped in try/except per plan section 9.7.
    On failure: dataclasses.replace the result's status to
    LAYER3_FAILED and return the pre-Layer-3 envelope. 100% coverage.
    * tests/test_geometry/test_generator_cad.py — invert the prior
    "Layer 3 unaffected"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
2026-05-26 Land Layer 2 fields_cad + wire into generator_cad
    * src/fanopt/geometry/fields_cad.py — five field-application functions
    in the locked sub-order TPMS -> noise -> louver -> texture -> edge,
    plus the apply_layer2_fields dispatcher. 96% line coverage from
    28 tests in tests/test_geometry/test_fields_cad.py.
    - TPMS: Phase-1 placeholder (regular grid of cylindrical through-
    holes at the gyroid cell pitch; honors cell_size_m and
    thickness_gradient). True triply-periodic minimal surfaces need
    marching cubes and are a Phase-2 refinement.
    - Noise: Phase-1 placeholder (deterministic sum-of-sines field
    thresholded so 1 - threshold_retention of cells are cut).
    - Louver / Te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
2026-05-26 Land manufacturability_cad — real CadQuery shape inspection
    * src/fanopt/geometry/manufacturability_cad.py — new module with
    run_manufacturability_filter_cad(shape, layer4). Walks all 14
    protocol rows of plan section 9.7.3. Phase-1 strategy per row:
    Real shape inspection (8/10 of the PENDING_CADQUERY rows):
    #2 overhang angle: planar face-normal scan, fail if any planar
    face faces > 45 deg past vertical.
    #3 single component: shape.solids() count == 1 (CRITICAL).
    #4 bridging: horizontal edges > 8 mm flagged.
    #5 internal voids: shape.isValid() + closed-shell check.
    #6 edge clearance: PASSED by schema (Layer 2 cuts kept in
    PANEL_X_CARVE_RANGE_M, Layer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
2026-05-26 Land fan_assembly + 3 orchestration scripts (Phase 1 completion)
    * src/fanopt/geometry/fan_assembly.py — deployed-fan composition
    helpers: deploy_fan() rotates the V-unit blade into N instances
    around the pivot; compute_mass_kg, compute_centre_of_mass,
    compute_i_wrist_kgm2 emit the physical properties the Phase 4 BO
    ledger and the deferred Spike 0.2 V2 cross-check consume.
    100% line coverage from 15 tests in
    tests/test_geometry/test_fan_assembly.py.
    * scripts/fan_addin.py — CLI exporter: params.json -> per-blade
    STLs + deployed-fan STEP. CadQuery-based; the plan's Fusion 360
    add-in label is preserved in the filename but the implementation
    doesn't require Fusion 360. 4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
2026-05-27 Phase 1 smoke + checklist update
    * docs/phase_logs/phase_1_smoke.md — shakedown record for the Phase 1
    CadQuery generator. Runs scripts/smoke_test.py + print_strategy.py
    + fan_addin.py on two representative designs (baseline flat panel +
    light-features: louver + L3 ellipsoid). Captures:
    - Per-design wall-times (~8 s smoke, ~6-12 s STL export) on M3.
    - Mass / I_wrist / manufacturability score per design.
    - The C9 100 g cap is tight even at schema-thinnest panel: baseline
    comes in at 153 g, light-features at 217 g. Aggressive Layer 2/3
    carving will be required for C9 compliance — Phase 4 BO objective.
    - The deployed fan (369 mm y-extent) does NOT fit a 256 mm b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
2026-05-27 Fix Spike 0.6d.2 moment-column priority: CMz before CMy
    The analyzer's _column() returns the FIRST candidate found in the
    history.csv keys. The prior candidate list ('cmy', 'cmz', 'cm',
    'cmoment') was written assuming the production 3D cfg's y-axis pitch
    convention. After the 2026-05-21 y->z cfg fix the 2D thin-plate
    template pitches about z, so CMz is the meaningful pitching moment.
    CMy is identically zero for a 2D x-y mesh (forces in-plane, no
    z-component → ∫(Fz·dx − Fx·dz) = 0), so probing it first silently
    returns all-zeros and the gate fires the misleading 'no moment
    column' message despite CMz being present with O(1e14) oscillation.
    Reorder to ('cmz', 'cm', 'cmoment', 'cmy') i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
2026-05-28 Cell 7 time-step diagnostic: halve f1's dt (steps/cycle 200 → 400)
    The 2026-05-28 inner-iter rerun (INNER_ITER=200) produced bit-identical
    output to the INNER_ITER=100 baseline, confirming SU2 had already
    converged at 100 inner iters per outer step. Inner-iter under-
    convergence is NOT the source of the 46% I_a(f1) vs I_a(f2) spread.
    Next hypothesis: time-step truncation error scales like (ω·dt)² for an
    oscillation. f1's absolute dt = T₁/200 = 2.5 ms is 2× f2's dt = 1.25 ms.
    Halving f1's dt (steps/cycle 200 → 400) brings its dt to 1.25 ms,
    matching f2's. If time-step is the bottleneck, I_a(f1) should drop
    toward I_a(f2) = 0.99e11.
    Cell 7 changes:
    * Add STEPS_PER_CYCLE_F1 / STEPS_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
2026-05-29 phase_checklist: mark Phase 0 dual gate as PASS
    Reflects the 2026-05-29 Colab outcome: data/spike_0_6c/PASS (0.6c.1
    cfg sanity, recovered via evidence path 2026-05-21) AND
    data/spike_0_6d/PASS (0.6d.2 freq-consistency rel_diff=0.0248 ≪ 0.25)
    both present on the Colab VM; launch_phase4.py --check returns 0;
    Phase 4 launch is formally unblocked.
    Updates:
    * "What's still open in Phase 0" — refreshed header date + status
    rows. 0.6c.1, 0.6d.2, and 0.7a all marked [x]. New top-of-section
    block summarises the dual-gate result.
    * 0.6c.1 detail section — status flipped from [~] to [x].
    * 0.6d code-status line — adds the three follow-on fixes that
    surfaced during the Colab run (y→z pi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
2026-05-29 gitignore: un-ignore Phase-0 spike PASS markers + result JSONs
    Cell 11 of colab_spike_0_6d.ipynb failed with `git add` exit 1 because
    the prior `data/` rule blanket-excluded everything inside the data
    directory and no negation could reach in (git docs: "It is not
    possible to re-include a file if a parent directory of that file is
    excluded"). Empirically: `git ls-files data/` was empty even though
    the existing `!data/.gitkeep` etc. negations suggested those files
    were meant to be tracked — the negations were dead.
    Fix: switch from `data/` to `data/*` so git recurses into the data
    tree, then layer explicit negations:
    * `!data/spike_0_*/` un-ignore the spike subdirectories
    * `data/sp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
2026-05-29 phase_0_signoff: Note 4 (dt finding + decision) + close action items
    Phase 0 close-out documentation. Adds a new Note 4 between Note 3 and
    the Sign-off section, and flips the action-items checklist at the
    bottom to reflect what actually happened during the week of
    2026-05-21 → 2026-05-29.
    Note 4 — Spike 0.6d.2 PASS + time-step finding + production-cfg
    decision (2026-05-29):
    * Captures the 2026-05-29 PASS result (rel_diff = 0.0248, well under
    the 0.25 gate tolerance) + the per-frequency I_a and damping ratios.
    * Walks the diagnostic timeline: baseline FAIL → cycle-stability rules
    out transients → INNER_ITER=200 bit-identical (rules out inner-iter
    under-convergence) → dt = T/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
2026-07-03 geometry: Path A+ thickness-grid panel field + cut Layer-2 porosity (V1-Slim S4/S1)
    Path A+ (S4): add ThicknessGridField (3x6 control-point grid + corrugation family), integrate through Layer1Params (replaces the 3-knot thickness spline) and the CadQuery generator's 2D per-(u,v) thickness evaluation. Uniform grid + zero corrugation = flat baseline (reachable, not forced); from_radial_knots bridges the legacy spline so bilinear-radial == the old linear spline and all prior geometry assertions hold.
    Porosity cut (S1): remove NoiseField/TpmsField + constants, their CadQuery field functions, generator dispatch, and manufacturability checks #9/#10. Layer 2 is now the 3 non-porous families {louve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
2026-07-03 cfg: fix slice_steady for SU2 8.0.1 (first real run) — TEMPERATURE_FS + AOA + low-Mach prec
    The 2D-slice steady cfg had never been run against SU2. First Colab run surfaced two parse errors: FREESTREAM_OPTION= REYNOLDS is invalid (-> TEMPERATURE_FS), and SU2 has no FREESTREAM_DIRECTION option (-> AOA; productive (-1,0)=AOA 180, return (+1,0)=AOA 0, C2 mapping preserved). Also add LOW_MACH_PREC (MACH~0.006 diverges without it). Renderer computes aoa_deg=atan2(dy,dx); slice tests updated.
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2026-07-03 phase4: process-based parallel CFD eval (fix gmsh-thread crash)
    Threads can't run the CFD objective: gmsh installs a main-thread-only signal
    handler and keeps a single global model, so ThreadPoolExecutor raised
    "signal only works in main thread" on Colab. Replace with a ProcessPoolExecutor
    and a picklable CfdObjective so each worker has its own main thread + isolated
    gmsh state. Verified end-to-end with real SU2 (2 evals / 2 procs at 186% CPU).
    Set BATCH_SIZE = N_WORKERS to parallelize the BO loop (q-batch qNEHVI), not just
    the DoE.
    Also: tqdm progress bar wired through run_campaign; Colab notebook updated with
    Drive checkpoint/resume, campaign knobs, and process-parallel defaults.
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2026-07-04 phase5: 3D SU2 verification pipeline + fix fan3d_steady cfg for SU2 8.0.1
    Bridge from the Phase-4 Pareto to high-fidelity verification, built in parallel
    with the campaign:
    - fanopt.cfd.mesh: 3D external-flow volume mesher (STEP body -> box-minus-body ->
    wall-refined tet mesh, fan_surface + farfield markers). Single V-unit blade —
    the full deployed fan's click-mating faces are non-manifold and won't tet-mesh.
    - fanopt.cfd.phase5 + scripts/run_phase5_verify.py: top-k diverse Pareto -> blade
    -> 3D unsteady SU2 -> canonical J_fan -> Kendall-tau check that the 2D-slice
    ranking survives the 3D physics (finite span / tip).
    - Fix fan3d_steady.cfg.j2: it used SU2-8.0.1-invalid FREESTREAM_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
2026-07-04 phase5: parallel per-design verification + Colab verification notebook
    - run_verification: n_workers runs the top-k designs concurrently in separate
    processes (picklable _VerifyWorker; gmsh can't be threaded). --workers CLI flag.
    Verified with real SU2 (2 designs / 2 procs, no signal error).
    - notebooks/colab_phase5_verify.ipynb: a dedicated 3D-verification runner to run on
    a SEPARATE Colab runtime in parallel with the Phase-4 campaign. Mounts Drive,
    reads the running campaign's checkpoint, verifies the current top-k in parallel,
    plots 2D-slice vs 3D J_fan. CPU only (no GPU). OMP/BLAS pinned to 1 thread/proc.
2026-07-04 phase4: fix BO crash on extreme-magnitude objectives + guard divergent evals
    Campaign died at the first BO iteration ("probability tensor contains inf/nan")
    after the DoE. Root cause reproduced: the unsteady J_fan is a nondimensionalized
    force ~1e12, and at that scale qNEHVI's hypervolume overflows to inf/nan, killing
    optimize_acqf's multinomial sampler. The GP's internal Standardize doesn't help
    because the acquisition + reference point run in the raw scale.
    - normalize_objectives / apply_objective_norm: center + unit-scale objectives to
    O(1) before fit_gp + qNEHVI (raw values kept for the Pareto). Fixes the crash.
    - sanitize_objectives: a divergent CFD eval (nan/inf J_fan) is replaced w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
2026-09-24 Clean up repo for GitHub: README, print guide, final 3D previews (#74)
    * chore: clean up repo for GitHub — README, print guide, final 3D previews
    - README rewritten for the V1 state (pipeline, status, ADR map, layout) with renders of
    the final print meshes; MIT LICENSE file added (pyproject already declared MIT)
    - docs/print_guide.md replaces the stale print_guide.html: final _ribadd files and the
    actual Bambu P2S slicer settings; print files move to a GitHub Release
    - docs/models/: decimated final blades (150k faces) for GitHub's 3D STL viewer
    - print_ready/ is now gitignored (local-only build outputs)
    - resolve stash-conflict markers left in V2_backlog.md and colab_fan_review.ipynb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
    [blade_00_final_preview.stl, blade_02_final_preview.stl, blade_03_final_preview.stl]
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
